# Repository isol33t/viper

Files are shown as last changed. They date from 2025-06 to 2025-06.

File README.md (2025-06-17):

# Duck Viper v1 PCB - Open Source Upgrade

⚠️ **Work in Progress** - This project is currently under development

Inspired by [Automated keyboard PCB design with ergogen and kbplacer by adamws](https://adamws.github.io/keyboard-pcb-design-with-ergogen-and-kbplacer/) & its [dockerfile](https://github.com/adamws/kicad-kbplacer/blob/develop/examples/absolem-ergogen/Dockerfile).

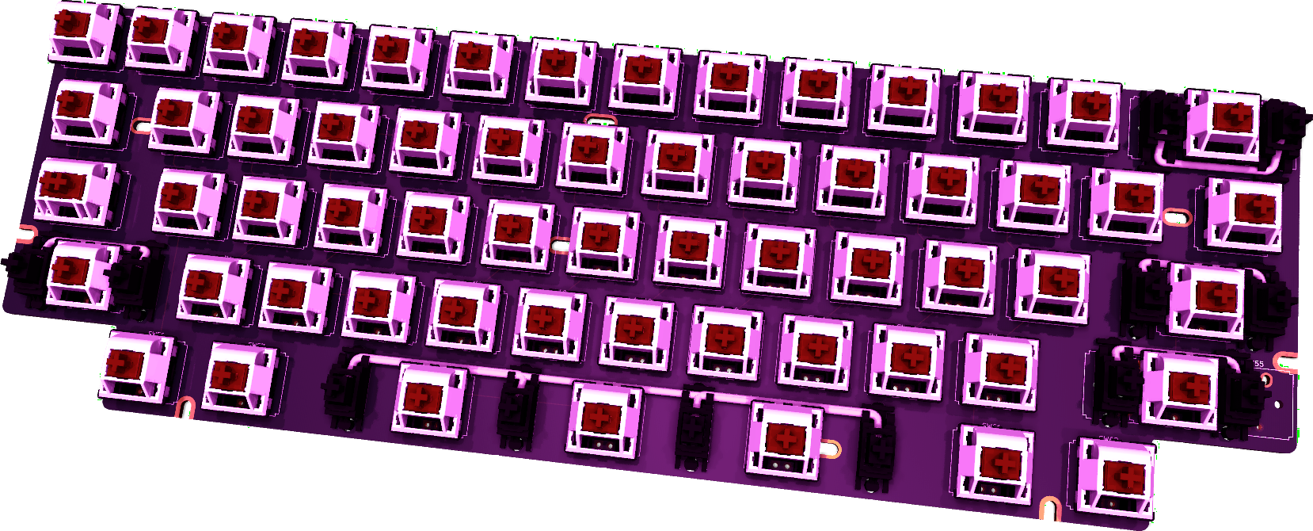
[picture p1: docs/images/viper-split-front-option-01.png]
Duck Viper v1 Render WIP


<!-- <img src="docs/images/viper-split-front-option-02.png" alt="Duck Viper v1 Render WIP" width="75%">

<img src="docs/images/viper-split-back-unrouted.png" alt="Duck Viper v1 Render WIP" width="75%"> -->

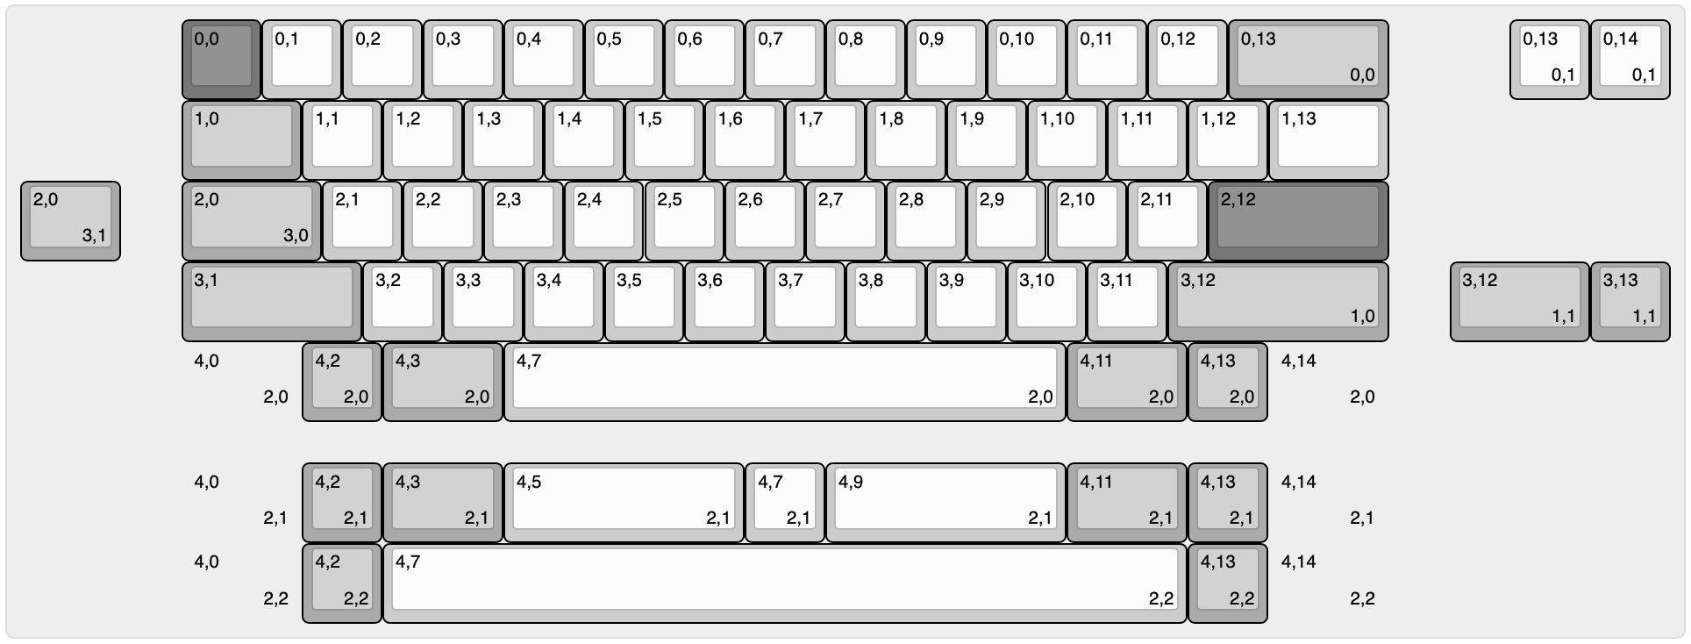
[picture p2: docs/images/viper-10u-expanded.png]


## Overview

An open-source PCB design for the Duck Viper v1 keyboard with hardware upgrades. This project focuses on transparency and community collaboration while building upon existing open-source resources.

**Disclaimer:** I'm not an electrical engineer - this project represents my attempt at "putting the parts together" using available community resources, guides, and libraries. Community feedback and contributions are greatly appreciated!

(Planned *) Upgrades: 
- USB-C Connector
- ESD
- Separate Caps Lock LED
- - RGB Underglow *
- - Additional switches for Split HHKB Bottom Row *
- - MXLockLed *

## Design Philosophy

- **Open Source First**: All design files, schematics, and documentation will be freely available
- **Community Driven**: Built using existing open-source libraries and community knowledge
- **Transparency**: Design decisions and trade-offs documented for others to learn from

## Current Status

<p align="left">
  Duck Viper v1 IC schematic WIP
</p>

[Link to PDF](hardware/schematic.pdf)

### Design Questions (Help Needed!)

**1. QFN vs QFP Package Decision**
- **QFN Pros**: Required for split HHKB layout with IC positioned between Caps Lock and A (see Voyager60 reference)
- **QFN Cons**: Hand soldering difficulty increases prototype cost (~$20 per PCB for 5-unit orders with just an assembled QFN IC vs ~$10 for 5 PCBs ex. assembly)
- **QFP**: Easier to hand solder but may not fit desired layout constraints due to additional stabilizer requirements for split HHKB

QFN IC placement mock-up:

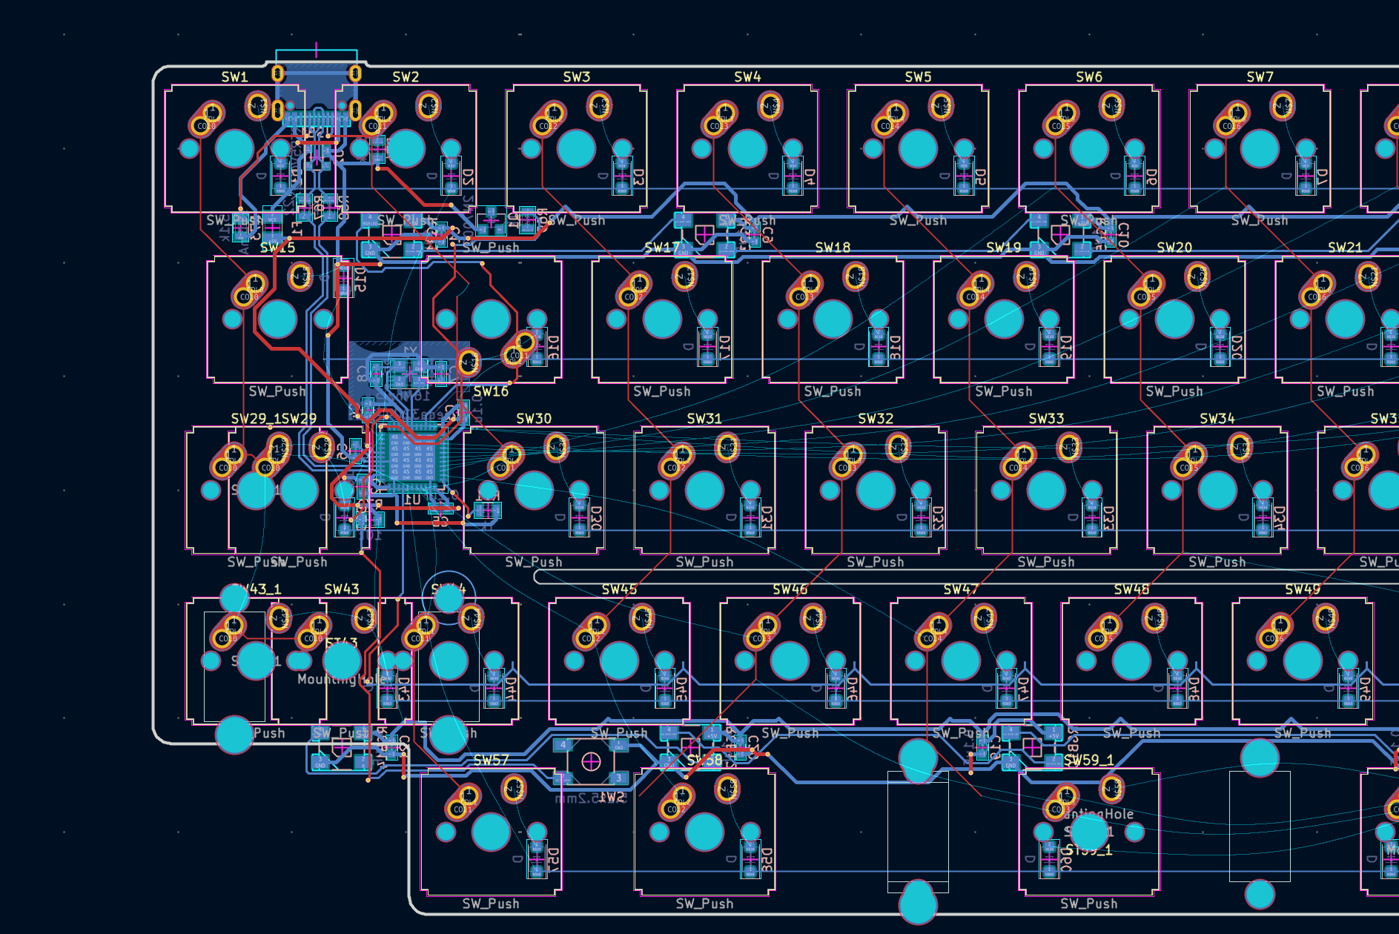
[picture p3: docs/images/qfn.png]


*If going QFN route, schematic verification help would be greatly appreciated!*

## Supported Layouts

kbplacer can use via for switch placement & requires via for collapsing a KLE layout

VIA spec https://www.caniusevia.com/docs/layouts#overview uses KLE raw, but not kle.com's raw json
VIA spec based on [wt60_d](https://github.com/the-via/keyboards/blob/9da730d66a00c3ca1b9b9ac7e7078fc221432501/v3/wilba_tech/wt60_d/wt60_d.json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)

```
python -m kbplacer.kle_serial -in -in kle/keyboard-layout-via-10u.json -inform KLE_VIA -out keyboard-layout-collapsed.json -outform KLE_RAW -collapse
```

- Forked [duck_viper](https://adamws.github.io/keyboard-pcbs/#duck-eagle_viper-v2-eagle_viper)

### Split HHKB, 10u

[KLE permalink](https://keyboard-layout-editor.com/##@@_x:2&c=%23777777%3B&=0,0&_c=%23cccccc%3B&=0,1&=0,2&=0,3&=0,4&=0,5&=0,6&=0,7&=0,8&=0,9&=0,10&=0,11&=0,12&_c=%23aaaaaa&w:2%3B&=0,13%0A%0A%0A0,0&_x:1.5&c=%23cccccc%3B&=0,13%0A%0A%0A0,1&=0,14%0A%0A%0A0,1%3B&@_x:2&c=%23aaaaaa&w:1.5%3B&=1,0&_c=%23cccccc%3B&=1,1&=1,2&=1,3&=1,4&=1,5&=1,6&=1,7&=1,8&=1,9&=1,10&=1,11&=1,12&_w:1.5%3B&=1,13%3B&@_c=%23aaaaaa&w:1.25%3B&=2,0%0A%0A%0A3,1&_x:0.75&w:1.75%3B&=2,0%0A%0A%0A3,0&_c=%23cccccc%3B&=2,1&=2,2&=2,3&=2,4&=2,5&=2,6&=2,7&=2,8&=2,9&=2,10&=2,11&_c=%23777777&w:2.25%3B&=2,12%3B&@_x:2&c=%23aaaaaa&w:2.25%3B&=3,1&_c=%23cccccc%3B&=3,2&=3,3&=3,4&=3,5&=3,6&=3,7&=3,8&=3,9&=3,10&=3,11&_c=%23aaaaaa&w:2.75%3B&=3,12%0A%0A%0A1,0&_x:0.75&w:1.75%3B&=3,12%0A%0A%0A1,1&=3,13%0A%0A%0A1,1%3B&@_x:2&w:1.5&d:true%3B&=4,0%0A%0A%0A2,0&=4,2%0A%0A%0A2,0&_w:1.5%3B&=4,3%0A%0A%0A2,0&_c=%23cccccc&w:7%3B&=4,7%0A%0A%0A2,0&_c=%23aaaaaa&w:1.5%3B&=4,11%0A%0A%0A2,0&=4,13%0A%0A%0A2,0&_w:1.5&d:true%3B&=4,14%0A%0A%0A2,0%3B&@_x:2&y:0.5&w:1.5&d:true%3B&=4,0%0A%0A%0A2,1&=4,2%0A%0A%0A2,1&_w:1.5%3B&=4,3%0A%0A%0A2,1&_c=%23cccccc&w:3%3B&=4,5%0A%0A%0A2,1&=4,7%0A%0A%0A2,1&_w:3%3B&=4,9%0A%0A%0A2,1&_c=%23aaaaaa&w:1.5%3B&=4,11%0A%0A%0A2,1&=4,13%0A%0A%0A2,1&_w:1.5&d:true%3B&=4,14%0A%0A%0A2,1%3B&@_x:2&w:1.5&d:true%3B&=4,0%0A%0A%0A2,2&=4,2%0A%0A%0A2,2&_c=%23cccccc&w:10%3B&=4,7%0A%0A%0A2,2&_c=%23aaaaaa%3B&=4,13%0A%0A%0A2,2&_w:1.5&d:true%3B&=4,14%0A%0A%0A2,2)

l33t

<details>
<summary>KLE Raw data, expanded</summary>
```
[{"x": 2, "c": "#777777"}, "0,0", {"c": "#cccccc"}, "0,1", "0,2", "0,3", "0,4", "0,5", "0,6", "0,7", "0,8", "0,9", "0,10", "0,11", "0,12", {"c": "#aaaaaa", "w": 2}, "0,13\n\n\n0,0", {"x": 1.5, "c": "#cccccc"}, "0,13\n\n\n0,1", "0,14\n\n\n0,1"],
[{"x": 2, "c": "#aaaaaa", "w": 1.5}, "1,0", {"c": "#cccccc"}, "1,1", "1,2", "1,3", "1,4", "1,5", "1,6", "1,7", "1,8", "1,9", "1,10", "1,11", "1,12", {"w": 1.5}, "1,13"],
[{"c": "#aaaaaa", "w": 1.25}, "2,0\n\n\n3,1", {"x": 0.75, "w": 1.75}, "2,0\n\n\n3,0", {"c": "#cccccc"}, "2,1", "2,2", "2,3", "2,4", "2,5", "2,6", "2,7", "2,8", "2,9", "2,10", "2,11", {"c": "#777777", "w": 2.25}, "2,12"],
[{"x": 2, "c": "#aaaaaa", "w": 2.25}, "3,1", {"c": "#cccccc"}, "3,2", "3,3", "3,4", "3,5", "3,6", "3,7", "3,8", "3,9", "3,10", "3,11", {"c": "#aaaaaa", "w": 2.75}, "3,12\n\n\n1,0", {"x": 0.75, "w": 1.75}, "3,12\n\n\n1,1", "3,13\n\n\n1,1"],
[{"x": 2, "w": 1.5, "d": true}, "4,0\n\n\n2,0", "4,2\n\n\n2,0", {"w": 1.5}, "4,3\n\n\n2,0", {"c": "#cccccc", "w": 7}, "4,7\n\n\n2,0", {"c": "#aaaaaa", "w": 1.5}, "4,11\n\n\n2,0", "4,13\n\n\n2,0", {"w": 1.5, "d": true}, "4,14\n\n\n2,0"],
[{"x": 2, "y": 0.5, "w": 1.5, "d": true}, "4,0\n\n\n2,1", "4,2\n\n\n2,1", {"w": 1.5}, "4,3\n\n\n2,1", {"c": "#cccccc", "w": 3}, "4,5\n\n\n2,1", "4,7\n\n\n2,1", {"w": 3}, "4,9\n\n\n2,1", {"c": "#aaaaaa", "w": 1.5}, "4,11\n\n\n2,1", "4,13\n\n\n2,1", {"w": 1.5, "d": true}, "4,14\n\n\n2,1"],
[{"x": 2, "w": 1.5, "d": true}, "4,0\n\n\n2,2", "4,2\n\n\n2,2", {"c": "#cccccc", "w": 10}, "4,7\n\n\n2,2", {"c": "#aaaaaa"}, "4,13\n\n\n2,2", {"w": 1.5, "d": true}, "4,14\n\n\n2,2"]
```
</details>

[KLE permalink](https://keyboard-layout-editor.com/##@@_x:2&c=%23777777%3B&=0,0&_c=%23cccccc%3B&=0,1&=0,2&=0,3&=0,4&=0,5&=0,6&=0,7&=0,8&=0,9&=0,10&=0,11&=0,12&_c=%23aaaaaa&w:2%3B&=0,13%0A%0A%0A0,0&_x:-2&c=%23cccccc%3B&=0,13%0A%0A%0A0,1&=0,14%0A%0A%0A0,1%3B&@_x:2&c=%23aaaaaa&w:1.5%3B&=1,0&_c=%23cccccc%3B&=1,1&=1,2&=1,3&=1,4&=1,5&=1,6&=1,7&=1,8&=1,9&=1,10&=1,11&=1,12&_w:1.5%3B&=1,13%3B&@_x:2&c=%23aaaaaa&w:1.75%3B&=2,0%0A%0A%0A3,0&_x:-1.75&w:1.25%3B&=2,0%0A%0A%0A3,1&_x:0.5&c=%23cccccc%3B&=2,1&=2,2&=2,3&=2,4&=2,5&=2,6&=2,7&=2,8&=2,9&=2,10&=2,11&_c=%23777777&w:2.25%3B&=2,12%3B&@_x:2&c=%23aaaaaa&w:2.25%3B&=3,1&_c=%23cccccc%3B&=3,2&=3,3&=3,4&=3,5&=3,6&=3,7&=3,8&=3,9&=3,10&=3,11&_c=%23aaaaaa&w:2.75%3B&=3,12%0A%0A%0A1,0&_x:-2.75&w:1.75%3B&=3,12%0A%0A%0A1,1&=3,13%0A%0A%0A1,1%3B&@_x:3.5%3B&=4,2%0A%0A%0A2,0&_w:1.5%3B&=4,3%0A%0A%0A2,0&_c=%23cccccc&w:3%3B&=4,5%0A%0A%0A2,1&_x:-3&w:7%3B&=4,7%0A%0A%0A2,0&_x:-3&w:3%3B&=4,9%0A%0A%0A2,1&_c=%23aaaaaa&w:1.5%3B&=4,11%0A%0A%0A2,0&=4,13%0A%0A%0A2,0)

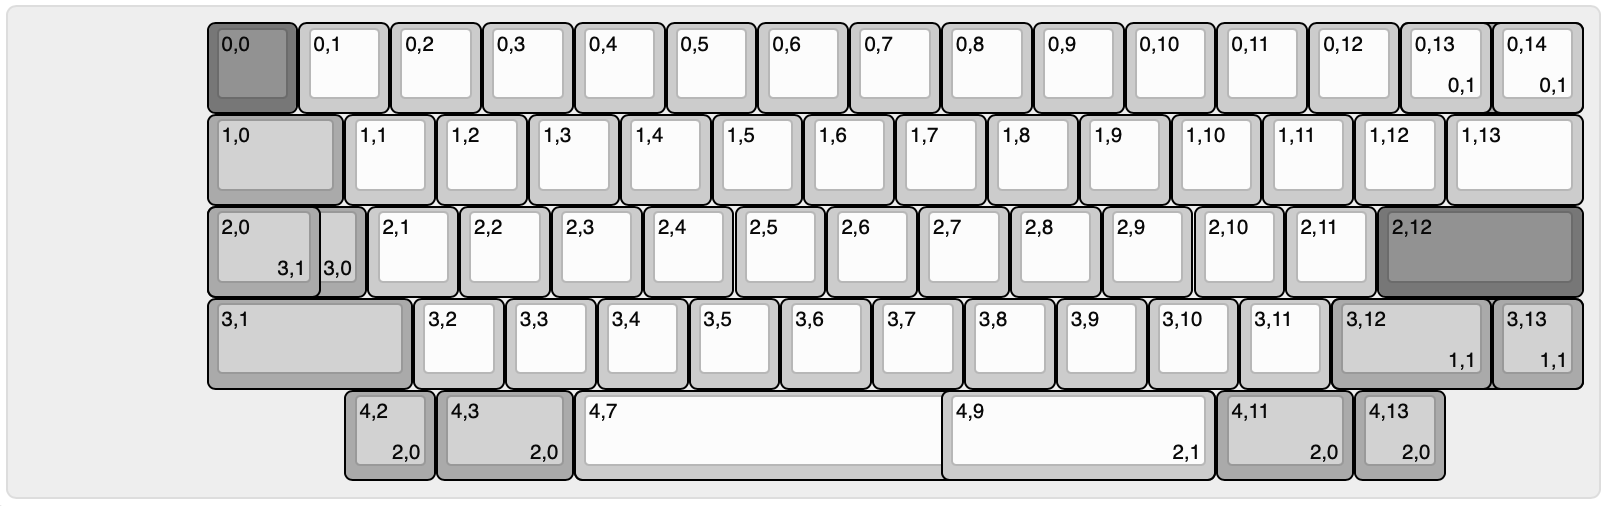
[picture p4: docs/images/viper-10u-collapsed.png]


<details>
<summary>KLE Raw data, collapsed</summary>
```
[{"x": 2, "c": "#777777"}, "0,0", {"c": "#cccccc"}, "0,1", "0,2", "0,3", "0,4", "0,5", "0,6", "0,7", "0,8", "0,9", "0,10", "0,11", "0,12", {"c": "#aaaaaa", "w": 2}, "0,13\n\n\n0,0", {"x": -2, "c": "#cccccc"}, "0,13\n\n\n0,1", "0,14\n\n\n0,1"],
[{"x": 2, "c": "#aaaaaa", "w": 1.5}, "1,0", {"c": "#cccccc"}, "1,1", "1,2", "1,3", "1,4", "1,5", "1,6", "1,7", "1,8", "1,9", "1,10", "1,11", "1,12", {"w": 1.5}, "1,13"],
[{"x": 2.0, "c": "#aaaaaa", "w": 1.75}, "2,0\n\n\n3,0", {"x": -1.75, "w": 1.25}, "2,0\n\n\n3,1", {"x": 0.5, "c": "#cccccc"}, "2,1", "2,2", "2,3", "2,4", "2,5", "2,6", "2,7", "2,8", "2,9", "2,10", "2,11", {"c": "#777777", "w": 2.25}, "2,12"],
[{"x": 2, "c": "#aaaaaa", "w": 2.25}, "3,1", {"c": "#cccccc"}, "3,2", "3,3", "3,4", "3,5", "3,6", "3,7", "3,8", "3,9", "3,10", "3,11", {"c": "#aaaaaa", "w": 2.75}, "3,12\n\n\n1,0", {"x": -2.75, "w": 1.75}, "3,12\n\n\n1,1", "3,13\n\n\n1,1"],
[{"x": 3.5}, "4,2\n\n\n2,0", {"w": 1.5}, "4,3\n\n\n2,0", {"c": "#cccccc", "w": 3}, "4,5\n\n\n2,1", {"x": -3.0, "w": 7}, "4,7\n\n\n2,0", {"x": -3.0, "w": 3}, "4,9\n\n\n2,1", {"c": "#aaaaaa", "w": 1.5}, "4,11\n\n\n2,0", "4,13\n\n\n2,0"]
```
</details>

## Development Environment Setup

### Hardware Design (KiCad)

**Requirements:**
- KiCad 9.0 or later
- Git for version control
- - python3
- - docker

**Setup:**
```bash
# Clone the repository
git clone [repository-url]
cd duck-viper-v1-pcb

# Open the project in KiCad
# File -> Open Project -> duck-viper-v1.kicad_pro
```

**Setup for adamws/kbplacer:**
```bash
# Clone the repository
git clone [repository-url]
cd duck-viper-v1-pcb
python3 -m venv .venv
source .venv/bin/activate
python3 -m pip install .

python -m kbplacer.kle_serial -in kle/keyboard-layout-via.json -inform KLE_VIA -out kle/keyboard-layout-collapsed.json -outform KLE_INTERNAL -collapse
python tools/layout2url.py -in keyboard-layout-collapsed.json|pbcopy

# Open the project in KiCad
# File -> Open Project -> duck-viper-v1.kicad_pro
```

**linux**
```bash
python3 -m venv .venv --system-site-packages
source .venv/bin/activate
pip install .

# test kicad
python -c "import pcbnew; print(pcbnew.Version())"
```

**Libraries Used:**
- [AcheronProject/AlexandriaLibrary](https://github.com/AcheronProject/AlexandriaLibrary)
- Community keyboard libraries (specific sources TBD)

### Firmware Development

*Detailed firmware setup instructions will be added as development progresses.*

### Manufacturing Files

Generation of Gerber files, pick-and-place files, and BOM will be documented once design is finalized.

## Acknowledgments

This project builds upon the incredible work of the open-source keyboard community. Specific libraries, guides, and resources used will be documented as the project progresses.

## Contributing

As a learning project, I welcome:
- Schematic reviews and feedback
- Design suggestions and improvements
- Documentation contributions
- Testing and validation help

## Thanks yo

This project is inspired by [Automated Keyboard PCB design with ergogen and kbplacer](https://github.com/adamws/kicad-kbplacer/tree/master/examples/absolem-ergogen). Still, it's far from being fully automated.

- adamws/kicad-kbplacer
- https://github.com/ruiqimao/keyboard-pcb-guide
- https://wiki.ai03.com/books/pcb-design
- https://github.com/evyd13/plain60-b
- https://github.com/evyd13/plain60-c
- https://www.masterzen.fr/2020/05/03/designing-a-keyboard-part-1/

## License

[MIT](LICENSE)

---

*This project is a learning exercise in PCB design. Use at your own risk and always verify designs before manufacturing.*

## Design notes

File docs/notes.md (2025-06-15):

# Duck Viper v1 - Design Notes

*Consolidated notes and research for the Duck Viper v1 PCB project*

## Design Decision Log

- 2025-05: restart PCB project
- - manual placement of basic viper pcb, no leds
- - discovered adamws/kicad-kbplacer
- - forked [4pplet/eagle_viper_rep_rev_b](https://adamws.github.io/keyboard-pcbs/#4pplet-eagle_viper_rep_rev_b)
- 2025-06:
- - added ws2818b leds
- - removed iso enter/split left shift
- - considering split hhkb layout
- - - requires qfn instead of qfp
- footprint placement
- - voyager60 usb-c
- - voyager60 qfn 
- - gh60 qfp
- [decoupling cap placement](https://components101.com/articles/decoupling-capacitor-vs-bypass-capacitors-working-and-applications)
- - The positioning involves two different capacitors, consider a capacitor of capacitance 10µF placed away from the IC which is used to smooth out the low frequency changes in the power supply and a 0.1 µF capacitor kept closer to the IC which is used to smooth the high frequency changes in the power supply.
- - 10µF placed away
- - .1µF close to pins
- - for voyager60: move 10µF cap further away
- - add additional .1µF cap where 10µF currently sits
- improve kicad docs
- nice template, https://github.com/nguyen-v/KiCAD_Templates/tree/master
- - eeschema
- - https://www.youtube.com/watch?v=_ZjyeltLMAg
- - pcbnew
- - https://www.youtube.com/watch?v=_ZjyeltLMAg&list=WL&index=109&t=1305s

You probably shouldn't connect the USB shield to GND, or if you do it should be through a cap and something like a 10M resistor. This is to avoid emitting unwanted RFI.
!
https://geekhack.org/index.php?topic=48851.msg2356672#msg2356672

- jp60
- - usb-c shield to earth, earth to ferrite bead to gnd
- tsuki
- - usb-c shield to junction, 1 to 4.7nF cap then gnd, another to 1M resistor then GND
- - no ferrite bead
- - mounting hole to case ESD
- - case mounting hole ESD to junction, 1 to 4.7nF cap then gnd, another to 1M resistor then GND
- https://geekhack.org/index.php?topic=48851.msg2361099#msg2361099
- - bpiphany: For the USB shield there seem to be as many different recommendations as there are possible ways to combine resistor/capacitor/inductor networks or directly tie it to GND or floating. It's hard to tell what to use when/where/why.
- ground plane crystal: https://geekhack.org/index.php?topic=48851.msg2406698#msg2406698
- - I think it's more about keeping the "noise" from the oscillator away from the plane. You ideally want to surround the oscillator circuit with ground, on the sides and below. You then connect this "cage" at a single point to the board ground plane.
- resistors for usb close to usb or mcu?
- - https://geekhack.org/index.php?topic=48851.msg2481179#msg2481179
- - ESD/EMI protection deivces should be placed near USB receptacle while termination(impedance matcning) resistors should be placed near controller.
- - We already know empirically that it doesn't matter very much for keyboards, though, this simple design guide will be still helpful for us.
- [Why does the ATmega32 have two VCC & GND pins?](https://microchip.my.site.com/s/article/Why-does-the-ATmega32-have-two-VCC-GND-pins)

- alternative docker idea
- create atmega template with linked sheets
- copy to docker build container
- create new schematics -> path of linked sheets
- - run save-schematic-script
- export netlist from schematic
- - includes linked sheets, in theory
- kinet2pcb complete netlist
- kbplacer/pos2orient/???

## Component Sourcing

I found a box of components, from a previous attempt, based on [evyd13/plain60-c](https://github.com/evyd13/plain60-c#bill-of-materials-bom), yet some are currently out ot stock.

- Stick with 0805 packages
- Asian brands are Okay
- x7r capacitors are preferred
- ... by a single brand, possibly hre?
- - uniroyal
- - nexperia
- - https://www.lcsc.com/supplier/featured-asian-brands
- - qfp https://www.lcsc.com/product-detail/Microcontrollers-MCU-MPU-SOC_Microchip-Tech-ATMEGA32U4-AU_C44854.html
- - qfn https://www.lcsc.com/product-detail/Microcontroller-Units-MCUs-MPUs-SOCs_Microchip-Tech-ATMEGA32U4-MU_C112161.html

## Quick Reference

### Key Decisions
- **Layout**: Split HHKB (requires QFN placement between Caps Lock and A)
- **Components**: 0805 package (already sourced but wrong dimensions, currently using SOD123 & QFP)
- **Connector**: USB-C (seems to fit!)
- **Microcontroller**: ATmega32U4 (QFN vs QFP decision pending)
- **Reference Design**: Tsuki, JP60, Voyager60, plain60-b/c

### Current Status
- ✅ Dev environment setup (Mac + Linux + Docker)
- ✅ KLE layouts created (collapsed/uncollapsed variants)
- ✅ Kbplacer and kle2netlist working
- ✅ Local library Git repo created
- ⚠️ **QFN prototyping cost: ~$17.60 per PCB** (PCBWay assembly)
- 🔄 Library decisions pending (Acheron vs others)
- 🔄 ESD protection component selection

---

## Development Environment ✅

### Tools Setup
- **Mac**: Python venv with kbplacer, pyyaml, pyurlon, kle2netlist
- **Linux**: KiCad global python modules + Docker support
- **Kbplacer**: Working with dockerized dev branch
- **Kle2netlist**: Integrated with ATmega template

### Workflows Tested
- ✅ Manual kbplacer-kicad workflow
- ✅ Dockerized development environment
- ✅ KLE → netlist → KiCad pipeline

---

## Layout & Mechanical ✅

### KLE Layouts Complete
- **Uncollapsed**: Raw, Internal, Via variants
- **Collapsed**: Raw, Internal variants
- **Screenshots and URLs**: Documented
- **Stepped Caps**: Measured and positioned
  - Regular to stepped caps offset: -4.7625mm
  - Stepped caps to edge: 11.58125mm
  - Grave (`) to stepped caps: x+2.38125, y+38.1

### PCB Outline Placement ✅
- **Position relative to K_TILDE**: X=133.35, Y=38.085
- **PCB Dimensions**: 285mm × 94.6mm

### Stabilizer Configuration
- **Normal**: Backspace
- **Flipped 180°**: Space, LShift, RShift, Enter
- **ISO**: ST28_1 270° (conflicts with WS2812B LED placement)

---

## Component Research

https://www.lcsc.com/product-detail/Diodes-ESD_STMicroelectronics_USBLC6-2SC6_USBLC6-2SC6_C7519.html

### Microcontroller Package Decision
**QFN (Current Choice):**
- ✅ Required for split HHKB (fits between Caps & A)
- ❌ Can't hand solder easily
- ❌ Assembly cost: $17.60 per PCB (5 PCBs via PCBWay)
- ✅ 5 QFN ATmegas already sourced

**QFP Alternative:**
- ✅ Hand solderable
- ❌ May not fit split HHKB layout constraints

### Component Packages & Sourcing
**Current Stock (Wrong Dimensions):**
- 0805 capacitors ✅
- 0805 resistors ✅
- USB-C connector ✅ (seems to fit!)
- 5× QFN ATmega32U4 ✅

**Component Updates Needed:**
- Update footprints from current to 0805
- All non-LED board parts sourced but need dimension fixes

### ESD Protection Options
**USBLC6-2SC6** (Current stock):
- Very low capacitance ESD protection
- STMicroelectronics part

**PRTR5V0U2X** (JP60 reference):
- Ultra low capacitance double rail-to-rail protection
- Nexperia part

**TPD2S017** (kle2netlist template):
- 2-channel 5.5V, 1pF, ±11kV protection with EMI filtering
- TI part

---

## Library Decisions (Pending)

### Symbol Libraries
- **Acheron**: Selected ✅
- Reference components from Tsuki schematic:
  - ResistorSMD 0603_1608Metric
  - CapSMD 0603
  - ATQFP44_10x10mm_P0.8
  - Crystal_SMD_3225-4Pin
  - SW_SPST_TL3342
  - SOT-23-6 ESD
  - USB_C_Receptacle_XKB_U262-16XN-4BVC11

### Footprint Libraries (To Decide)
- **Acheron**: Connectors, mounting holes
- **Kiswitch**: Connectors, stabilizers  
- **MX_V2**: Switch LEDs
- **Local lib**: Viper outline ✅

### Local Library ✅
- Viper outline ✅
- ISP header (needed? QMK has soft reset)
- Crystal (custom 3-pad vs 4-pad - why?)
- Mounting holes (Acheron reference)
- USB connectors

---

## LED Matrix & RGB

### Switch LEDs ✅
- Circuit tested with old Viper repo
- Separate circuit for Caps Lock LED planned

### RGB LEDs (WS2812B)
**Component**: TZ_3528S2RGB_5V (JLCPCB: C26159669)
- 3528 format footprint
- **Conflict**: ISO Enter OR RGB LEDs (choosing RGB)
- Reference circuits: Tsuki, Voyager
- VCC/VDD/5V power considerations

### LED Matrix Integration ✅
- Successfully added 2x2 LED matrix to test
- ATmega template integration working

---

## Manufacturing Planning

### Assembly Costs
- **QFN Assembly**: $88 for 5 PCBs (PCBWay) = $17.60 each
- Cost excludes MCU component cost
- QFN hand soldering attempted but challenging

### PCB Specifications
- **Connector**: USB-C (fits in current design)
- **ESD**: Update schematic for chosen component
- **Finish**: Research Viper/Sprit/GH60 comparisons needed

---

## Future Features & Improvements

### Planned Features
- **MX Lock Caps**: LED support (reference: GH60PCB)
- **STM32 Variants**: Joker48/64 circuitry reference
- **Split HHKB**: Additional layout exploration

### Key Mapping & Special Keys
**Flipped Keys** (from bad/viper_v1):
- KC_GRV, KC_1, KC_2, KC_Q
- KC_CAPS, KC_CAPS_STEP, KC_A, KC_H
- KC_SHIFT, KC_SHIFT_SHORT, KC_ISO, KC_Z
- KC_SPACE, KC_RIGHT_ALT

---

## Completed Tasks ✅

### Development Setup
- [x] Local lib Git repo
- [x] Viper outline
- [x] ISP header
- [x] Cleanup repos (Viper, Voyager, Keebio, GH60, STM32 LED matrix)
- [x] Dev environment (Mac + Linux)
- [x] KLE layouts (all variants)
- [x] Kbplacer-KiCad integration
- [x] LED matrix testing
- [x] 2x2 test PCB with LED matrix + ATmega template

### Measurements & Positioning
- [x] Stepped caps measurements and positioning
- [x] PCB outline placement calculations
- [x] Key matrix positioning

---

## Pending Tasks

### Critical Path
- [ ] Finalize library decisions (Acheron vs alternatives)
- [ ] Test libraries in dockerized environment
- [ ] Complete RGB LED integration (non-ISO)
- [ ] Stabilizer placement (normal + flipped orientations)
- [ ] Component dimension updates (0805 transition)

### Secondary
- [ ] Schematic verification (community help needed)
- [ ] USB D+/D- net naming
- [ ] ATmega pin assignments optimization
- [ ] Assembly cost optimization research

---

## References & Resources

### Key Projects
- **Tsuki**: Primary schematic reference ⭐
- **Voyager60**: QFN placement reference
- **Keebio**: Component references
- **GH60**: Finish comparisons

### Tools & Documentation
- [Keyboard PCB Design Guide](https://adamws.github.io/keyboard-pcb-design-with-ergogen-and-kbplacer/)
- [KLE](https://www.keyboard-layout-editor.com)
- [KLE Converter](https://keyboard-tools.xyz/kle-converter)
- [kle2netlist](https://github.com/adamws/kle2netlist/tree/develop)
- [Via Layout Docs](https://www.caniusevia.com/docs/layouts/)
- [AI03 PCB Design Wiki](https://wiki.ai03.com/books/pcb-design/page/microcontroller-design)
- [Kbplacer Annotation Guide](https://github.com/adamws/kicad-kbplacer/blob/master/docs/annotation_guide.md)
- [masterzen design guide](https://www.masterzen.fr/2020/05/03/designing-a-keyboard-part-1/)

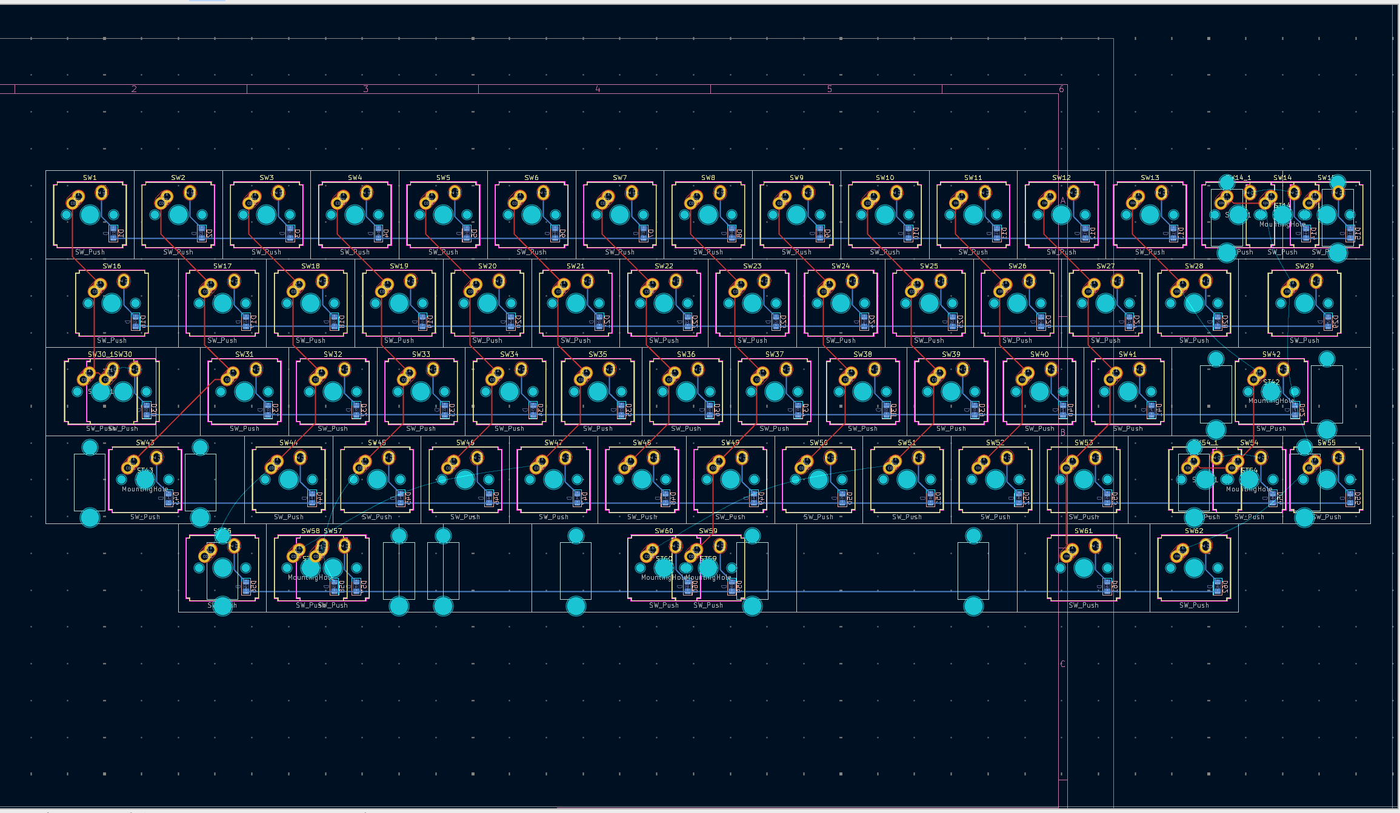
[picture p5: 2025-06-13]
docs/images/broken-bottom.png

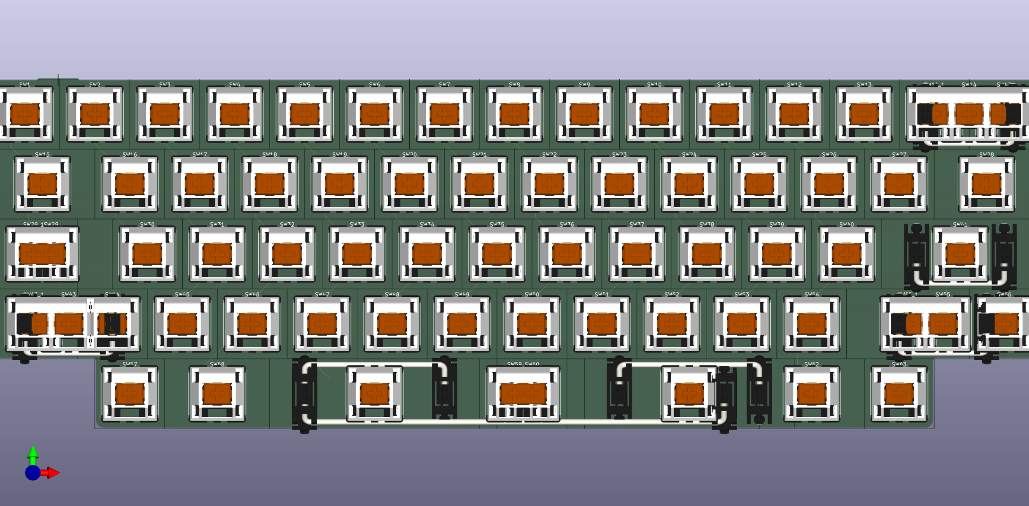
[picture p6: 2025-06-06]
docs/images/render.png

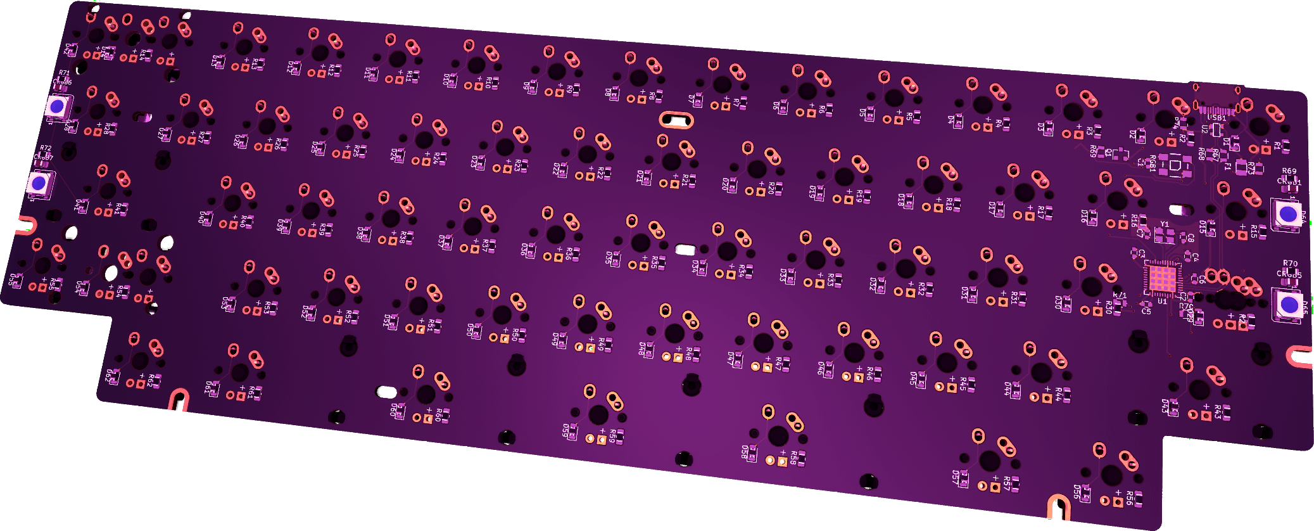
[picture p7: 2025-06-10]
docs/images/viper-split-back-unrouted.png

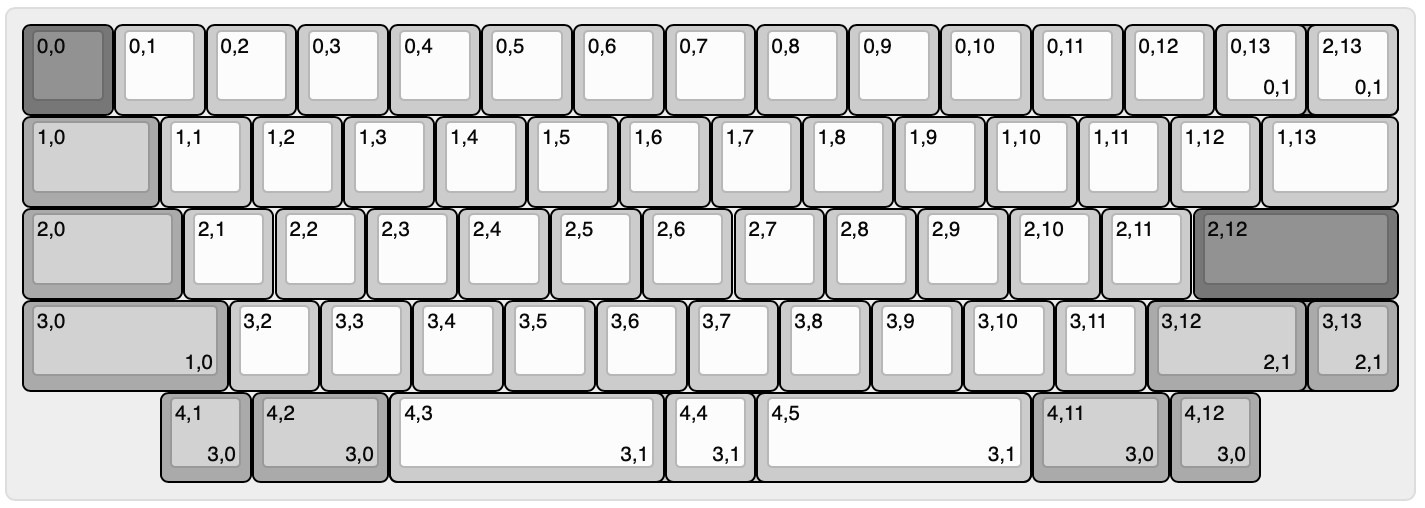
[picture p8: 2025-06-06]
docs/images/split-collapsed.png

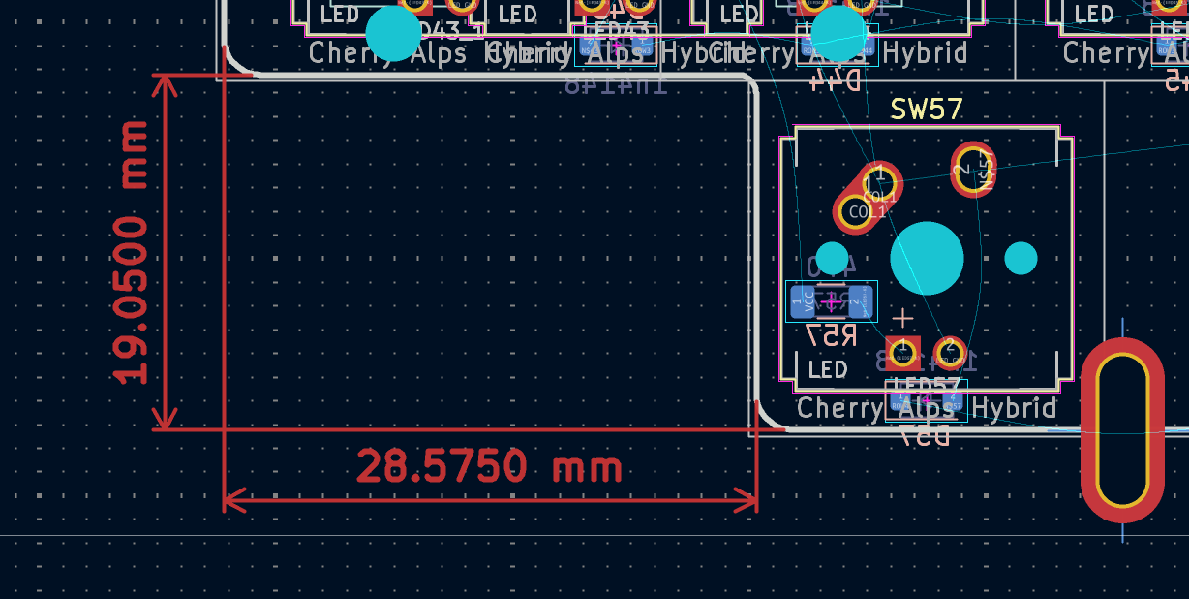
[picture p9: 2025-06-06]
docs/images/viper.png

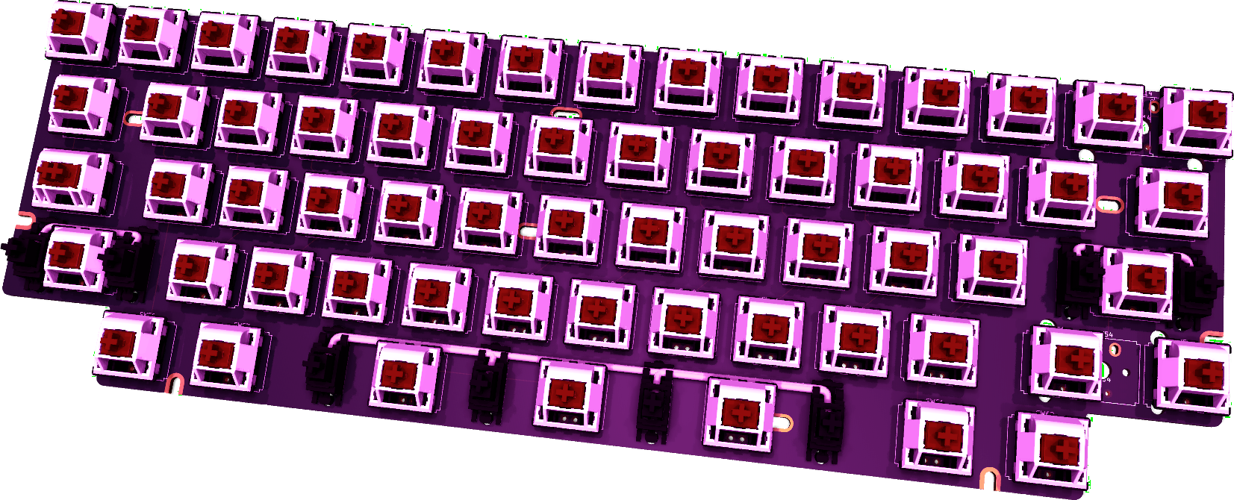
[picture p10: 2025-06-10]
docs/images/viper-split-front-option-02.png

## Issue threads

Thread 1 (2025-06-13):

PCB output from docker build has incorrect layout

isol33t, 2025-06-13:
TL;DR:
- currently, kbplacer in a docker (or locally for that matter, using kicad9.0.2 with kbplacer from PCM on macOS 15.4.1) places additional bottom row switches incorrectly.
- the 8u stabiliser is missing from automated builds

When I try to use [docker](https://github.com/isol33t/viper/blob/dev-kle2netlist/hardware/Dockerfile) to [build a PCB](https://github.com/isol33t/viper/blob/4d931042c1d1a1473b27abfa2af59fe0bfbce6e7/hardware/viper-10u-2025-06-13_11-10-14/viper-10u.kicad_pcb) with a [annotated VIA layout](https://github.com/isol33t/viper/blob/4d931042c1d1a1473b27abfa2af59fe0bfbce6e7/hardware/kle/keyboard-layout-via.json) which is collapsed during the build process, I notice the following:
- Additional bottom row switches and their stabilizers for a split HHKB layout (2x 3U) aren't placed correct.
- The additional 8u stabilizer is missing.
- Switches with overlapping footprints have a value such as SW30 SW30_1, still totaling 65 switches.

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

When I use the [kle.json](https://github.com/isol33t/viper/blob/4d931042c1d1a1473b27abfa2af59fe0bfbce6e7/hardware/viper-10u-2025-06-13_11-10-14/viper-10u-kle.json) from my build & submit it to [keyboard-tools.xyz](http://keyboard-tools.xyz), the bottom row is placed correct, yet there are 2 changes compared to the dockerbuild (as far as I can tell):
- Switch values just count from 1 to 65
- The kle.json file has been re-annotated, for instance, `backspace` becomes `0,16` & the color of  `\|` changes to `#aaaaaa` (which makes it a modifier key in the via spec)

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

Converting the [kle.json](https://github.com/isol33t/viper/blob/4d931042c1d1a1473b27abfa2af59fe0bfbce6e7/hardware/6d52fe96-3577-438b-9c42-944a9f39cb8f/keyboard/keyboard.json) from keyboard-tools.xyzs output to [`KLE_RAW`](https://github.com/isol33t/viper/blob/4d931042c1d1a1473b27abfa2af59fe0bfbce6e7/hardware/6d52fe96-3577-438b-9c42-944a9f39cb8f/keyboard/keyboard-raw.json) & submitting it my docker build gives me the same result.

- [KLE Expanded](https://keyboard-layout-editor.com/##@@_x:2&c=%23777777%3B&=0,0&_c=%23cccccc%3B&=0,1&=0,2&=0,3&=0,4&=0,5&=0,6&=0,7&=0,8&=0,9&=0,10&=0,11&=0,12&_c=%23aaaaaa&w:2%3B&=0,13%0A%0A%0A0,0&_x:1.5&c=%23cccccc%3B&=0,13%0A%0A%0A0,1&=0,14%0A%0A%0A0,1%3B&@_x:2&c=%23aaaaaa&w:1.5%3B&=1,0&_c=%23cccccc%3B&=1,1&=1,2&=1,3&=1,4&=1,5&=1,6&=1,7&=1,8&=1,9&=1,10&=1,11&=1,12&_w:1.5%3B&=1,13%3B&@_c=%23aaaaaa&w:1.25%3B&=2,0%0A%0A%0A3,1&_x:0.75&w:1.75%3B&=2,0%0A%0A%0A3,0&_c=%23cccccc%3B&=2,1&=2,2&=2,3&=2,4&=2,5&=2,6&=2,7&=2,8&=2,9&=2,10&=2,11&_c=%23777777&w:2.25%3B&=2,12%3B&@_x:2&c=%23aaaaaa&w:2.25%3B&=3,1&_c=%23cccccc%3B&=3,2&=3,3&=3,4&=3,5&=3,6&=3,7&=3,8&=3,9&=3,10&=3,11&_c=%23aaaaaa&w:2.75%3B&=3,12%0A%0A%0A1,0&_x:0.75&w:1.75%3B&=3,12%0A%0A%0A1,1&=3,13%0A%0A%0A1,1%3B&@_x:2&w:1.5&d:true%3B&=4,0%0A%0A%0A2,0&=4,2%0A%0A%0A2,0&_w:1.5%3B&=4,3%0A%0A%0A2,0&_c=%23cccccc&w:7%3B&=4,7%0A%0A%0A2,0&_c=%23aaaaaa&w:1.5%3B&=4,11%0A%0A%0A2,0&=4,13%0A%0A%0A2,0&_w:1.5&d:true%3B&=4,14%0A%0A%0A2,0%3B&@_x:2&y:0.5&w:1.5&d:true%3B&=4,0%0A%0A%0A2,1&=4,2%0A%0A%0A2,1&_w:1.5%3B&=4,3%0A%0A%0A2,1&_c=%23cccccc&w:3%3B&=4,5%0A%0A%0A2,1&=4,7%0A%0A%0A2,1&_w:3%3B&=4,9%0A%0A%0A2,1&_c=%23aaaaaa&w:1.5%3B&=4,11%0A%0A%0A2,1&=4,13%0A%0A%0A2,1&_w:1.5&d:true%3B&=4,14%0A%0A%0A2,1%3B&@_x:2&w:1.5&d:true%3B&=4,0%0A%0A%0A2,2&=4,2%0A%0A%0A2,2&_c=%23cccccc&w:10%3B&=4,7%0A%0A%0A2,2&_c=%23aaaaaa%3B&=4,13%0A%0A%0A2,2&_w:1.5&d:true%3B&=4,14%0A%0A%0A2,2)
- [KLE collapsed](https://keyboard-layout-editor.com/##@@_x:2&c=%23777777%3B&=0,0&_c=%23cccccc%3B&=0,1&=0,2&=0,3&=0,4&=0,5&=0,6&=0,7&=0,8&=0,9&=0,10&=0,11&=0,12&_c=%23aaaaaa&w:2%3B&=0,13%0A%0A%0A0,0&_x:-2&c=%23cccccc%3B&=0,13%0A%0A%0A0,1&=0,14%0A%0A%0A0,1%3B&@_x:2&c=%23aaaaaa&w:1.5%3B&=1,0&_c=%23cccccc%3B&=1,1&=1,2&=1,3&=1,4&=1,5&=1,6&=1,7&=1,8&=1,9&=1,10&=1,11&=1,12&_w:1.5%3B&=1,13%3B&@_x:2&c=%23aaaaaa&w:1.75%3B&=2,0%0A%0A%0A3,0&_x:-1.75&w:1.25%3B&=2,0%0A%0A%0A3,1&_x:0.5&c=%23cccccc%3B&=2,1&=2,2&=2,3&=2,4&=2,5&=2,6&=2,7&=2,8&=2,9&=2,10&=2,11&_c=%23777777&w:2.25%3B&=2,12%3B&@_x:2&c=%23aaaaaa&w:2.25%3B&=3,1&_c=%23cccccc%3B&=3,2&=3,3&=3,4&=3,5&=3,6&=3,7&=3,8&=3,9&=3,10&=3,11&_c=%23aaaaaa&w:2.75%3B&=3,12%0A%0A%0A1,0&_x:-2.75&w:1.75%3B&=3,12%0A%0A%0A1,1&=3,13%0A%0A%0A1,1%3B&@_x:3.5%3B&=4,2%0A%0A%0A2,0&_w:1.5%3B&=4,3%0A%0A%0A2,0&_c=%23cccccc&w:3%3B&=4,5%0A%0A%0A2,1&_x:-3&w:7%3B&=4,7%0A%0A%0A2,0&_x:-3&w:3%3B&=4,9%0A%0A%0A2,1&_c=%23aaaaaa&w:1.5%3B&=4,11%0A%0A%0A2,0&=4,13%0A%0A%0A2,0)
- [docker build log](https://github.com/isol33t/viper/tree/3cb8e976255d5e0f26320280a03c054df501b68b/hardware/viper-10u-2025-06-13_11-10-14)
- [keyboard-tools.xyz log](https://github.com/isol33t/viper/blob/3cb8e976255d5e0f26320280a03c054df501b68b/hardware/6d52fe96-3577-438b-9c42-944a9f39cb8f/logs/build.log)

ps. [via doesn't support stepped keys](https://www.caniusevia.com/docs/layouts/#kle-json-rules), something to look into later.

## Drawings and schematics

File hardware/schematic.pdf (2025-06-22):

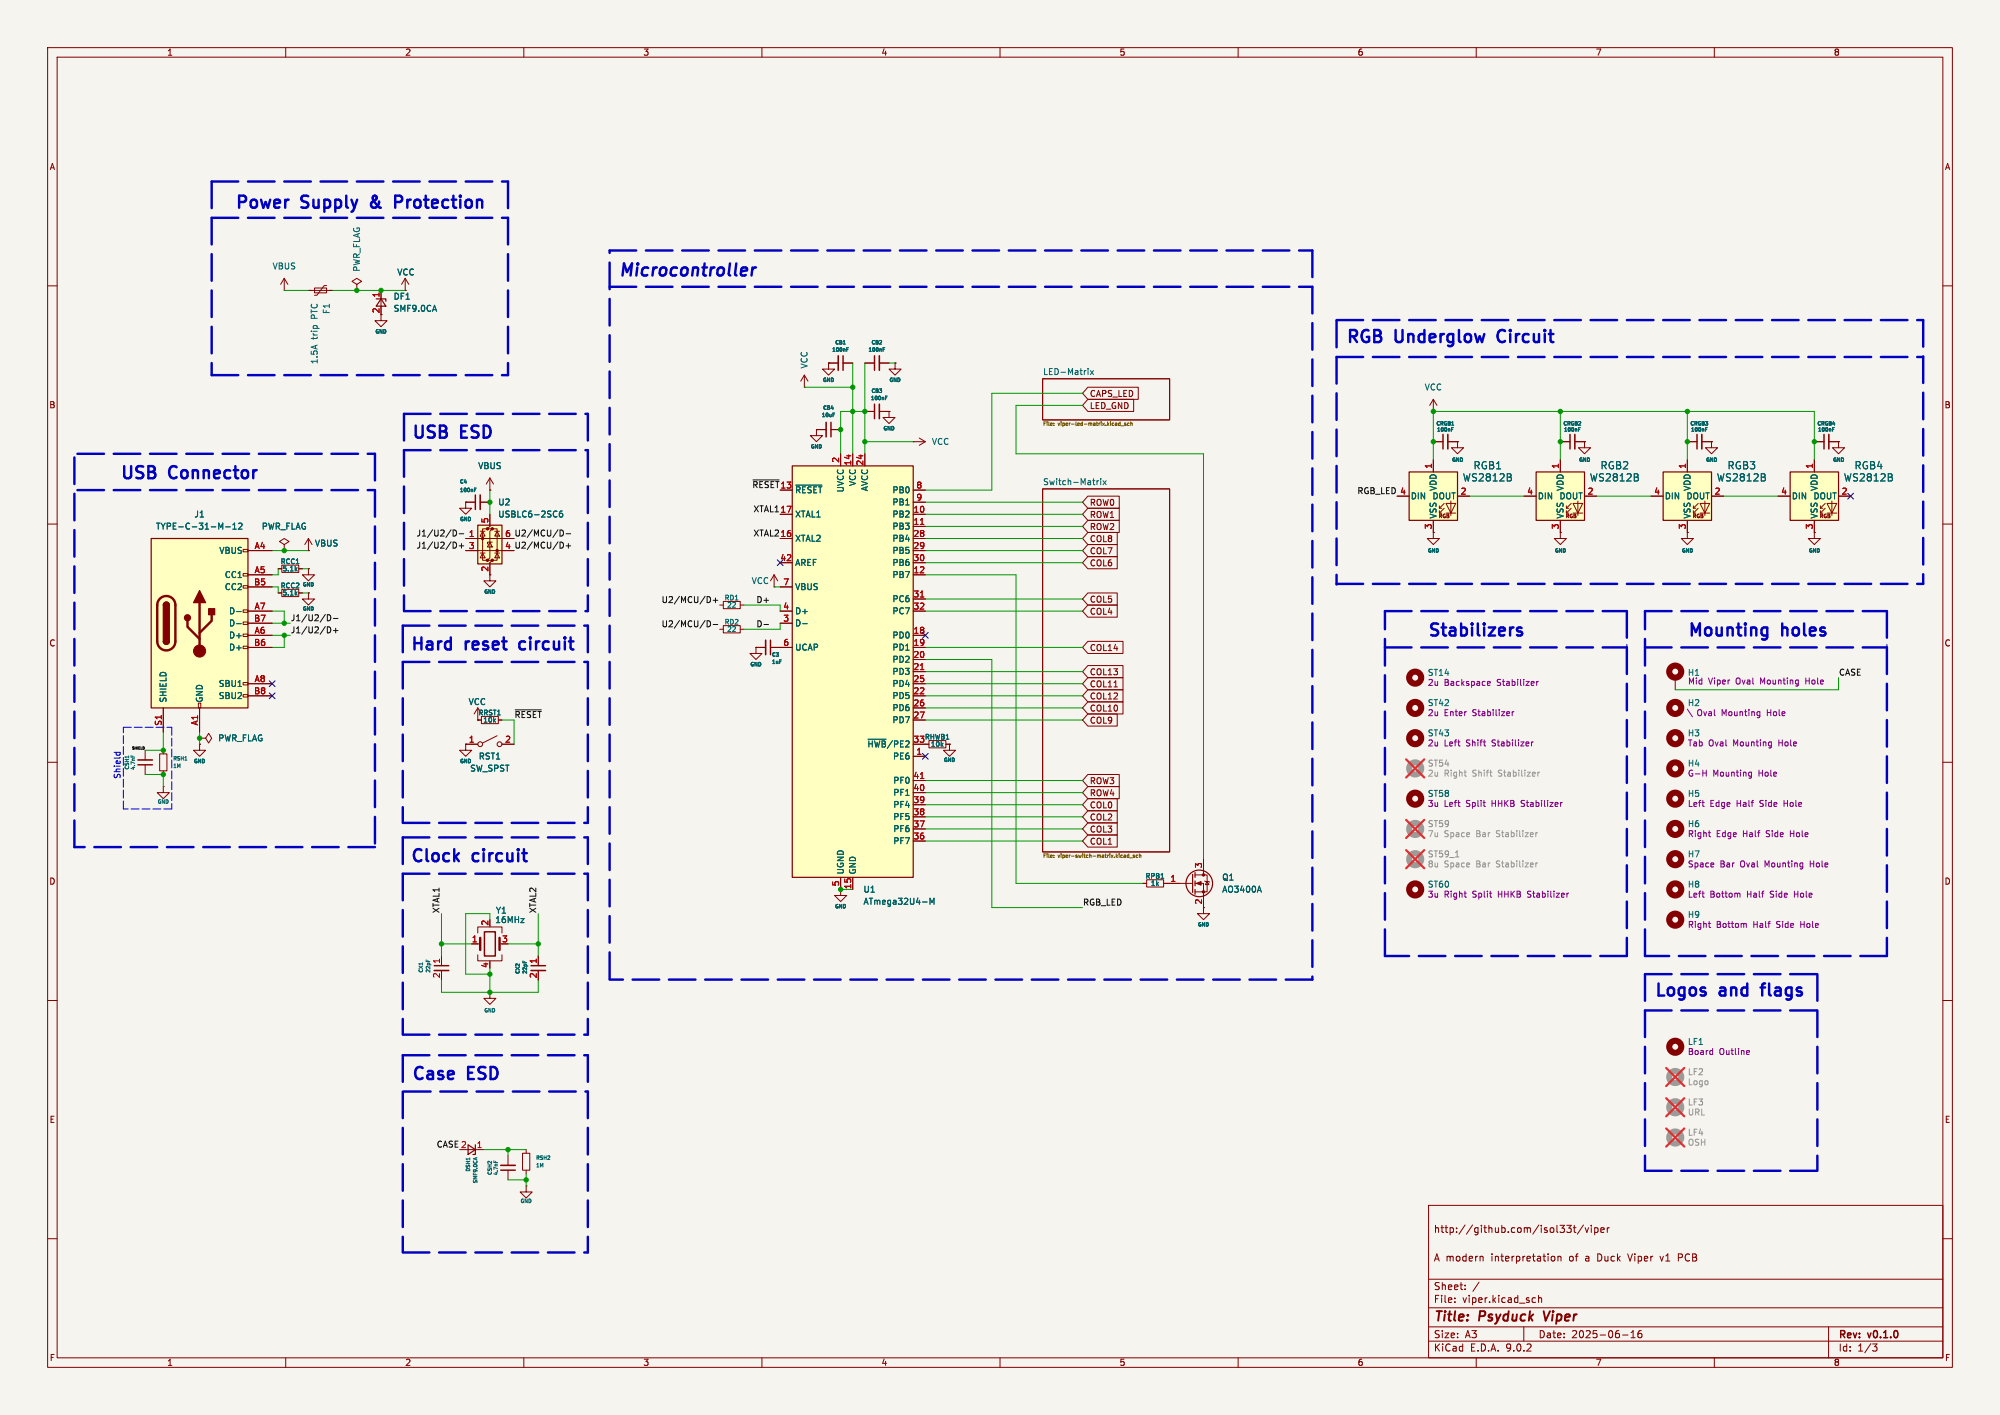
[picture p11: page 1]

5 VCC 14 GND 15 AVCC 24 PB0 8 PB1 9 PB2 10 PB3 11 PB4 28 PB5 29 PB6 30 PB7 12 PC6 31 PC7 32 PD0 18 PD1 19 PD2 20 PD3 21 PD4 25 PD5 22 PD6 26 PD7 27 ~{HWB}/PE233 PE6 1 PF0 41 PF1 40 PF4 39 PF5 38 PF6 37 PF7 36 U1ATmega32U4-M

5 VCC 14 GND 15 AVCC 24 PB0 8 PB1 9 PB2 10 PB3 11 PB4 28 PB5 29 PB6 30 PB7 12 PC6 31 PC7 32 PD0 18 PD1 19 PD2 20 PD3 21 PD4 25 PD5 22 PD6 26 PD7 27 ~{HWB}/PE233 PE6 1 PF0 41 PF1 40 PF4 39 PF5 38 PF6 37 PF7 36 RHWB1

Left Bottom Half Side Hole H1 Mid Viper Oval Mounting Hole RD1

3u Left Split HHKB Stabilizer ST14

H4 G-H Mounting Hole H2
\ Oval Mounting Hole H3 Tab Oval Mounting Hole H5

Left Edge Half Side Hole

1 2CX2 22pF GND H6 Right Edge Half Side Hole H9 Right Bottom Half Side Hole H7Space Bar Oval Mounting Hole

File: viper-switch-matrix.kicad_sch

3u Right Split HHKB Stabilizer

http://github.com/isol33t/viper

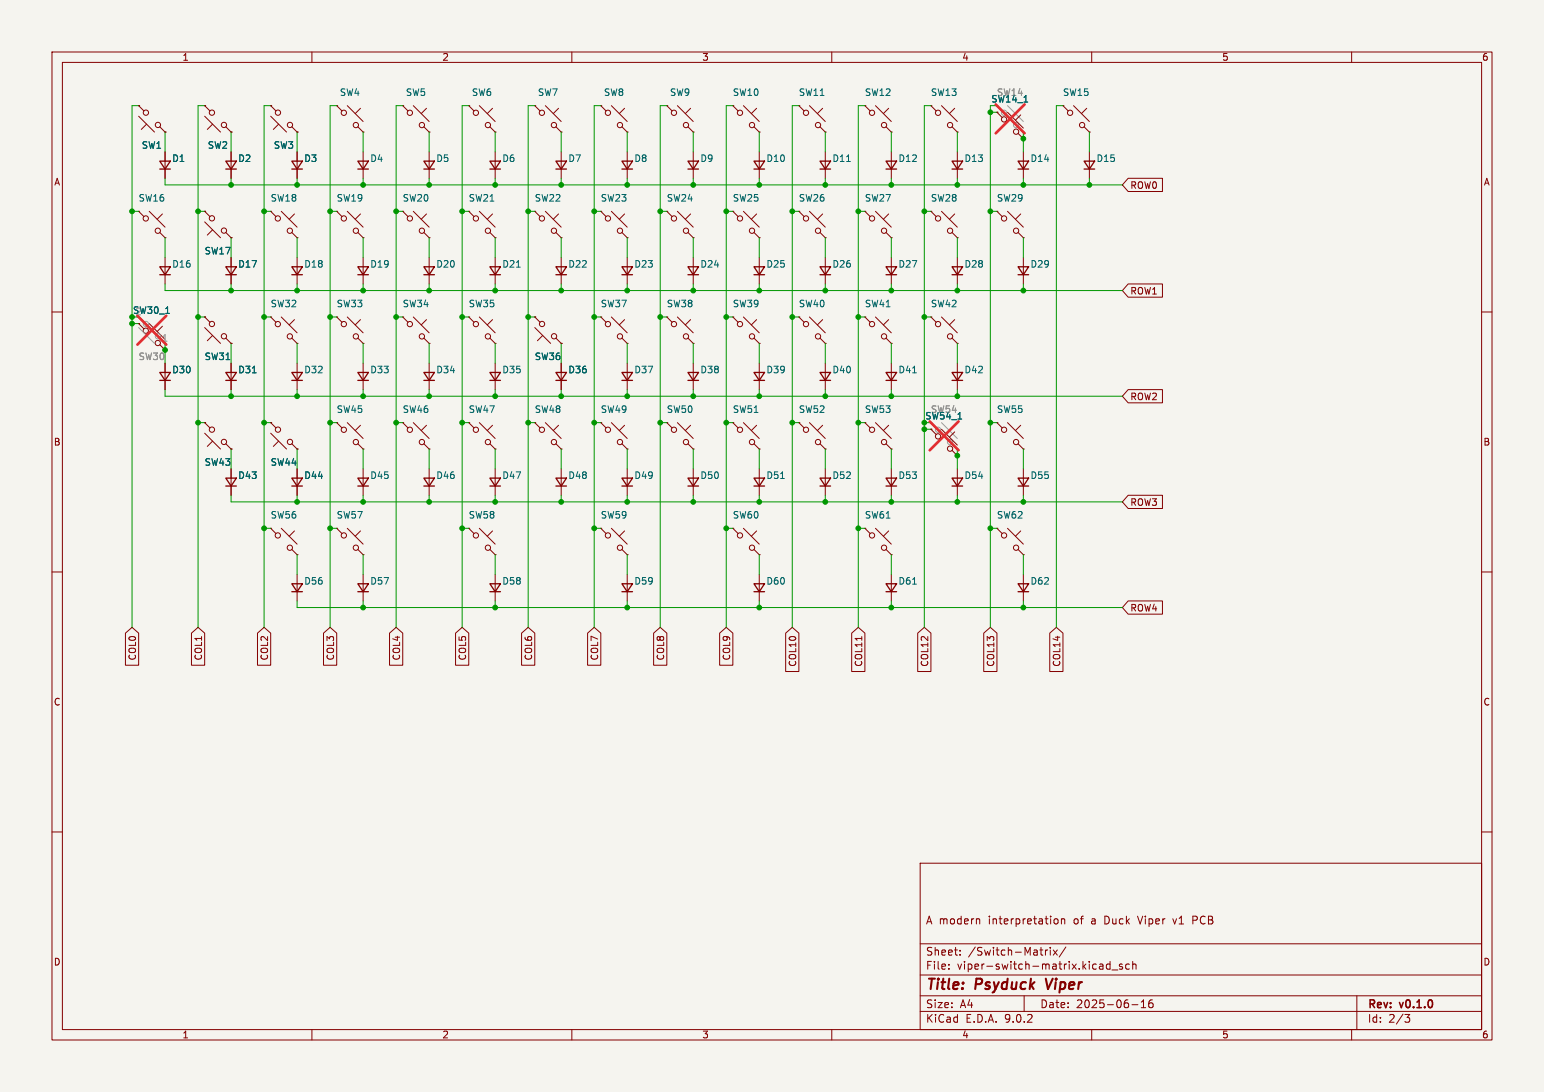
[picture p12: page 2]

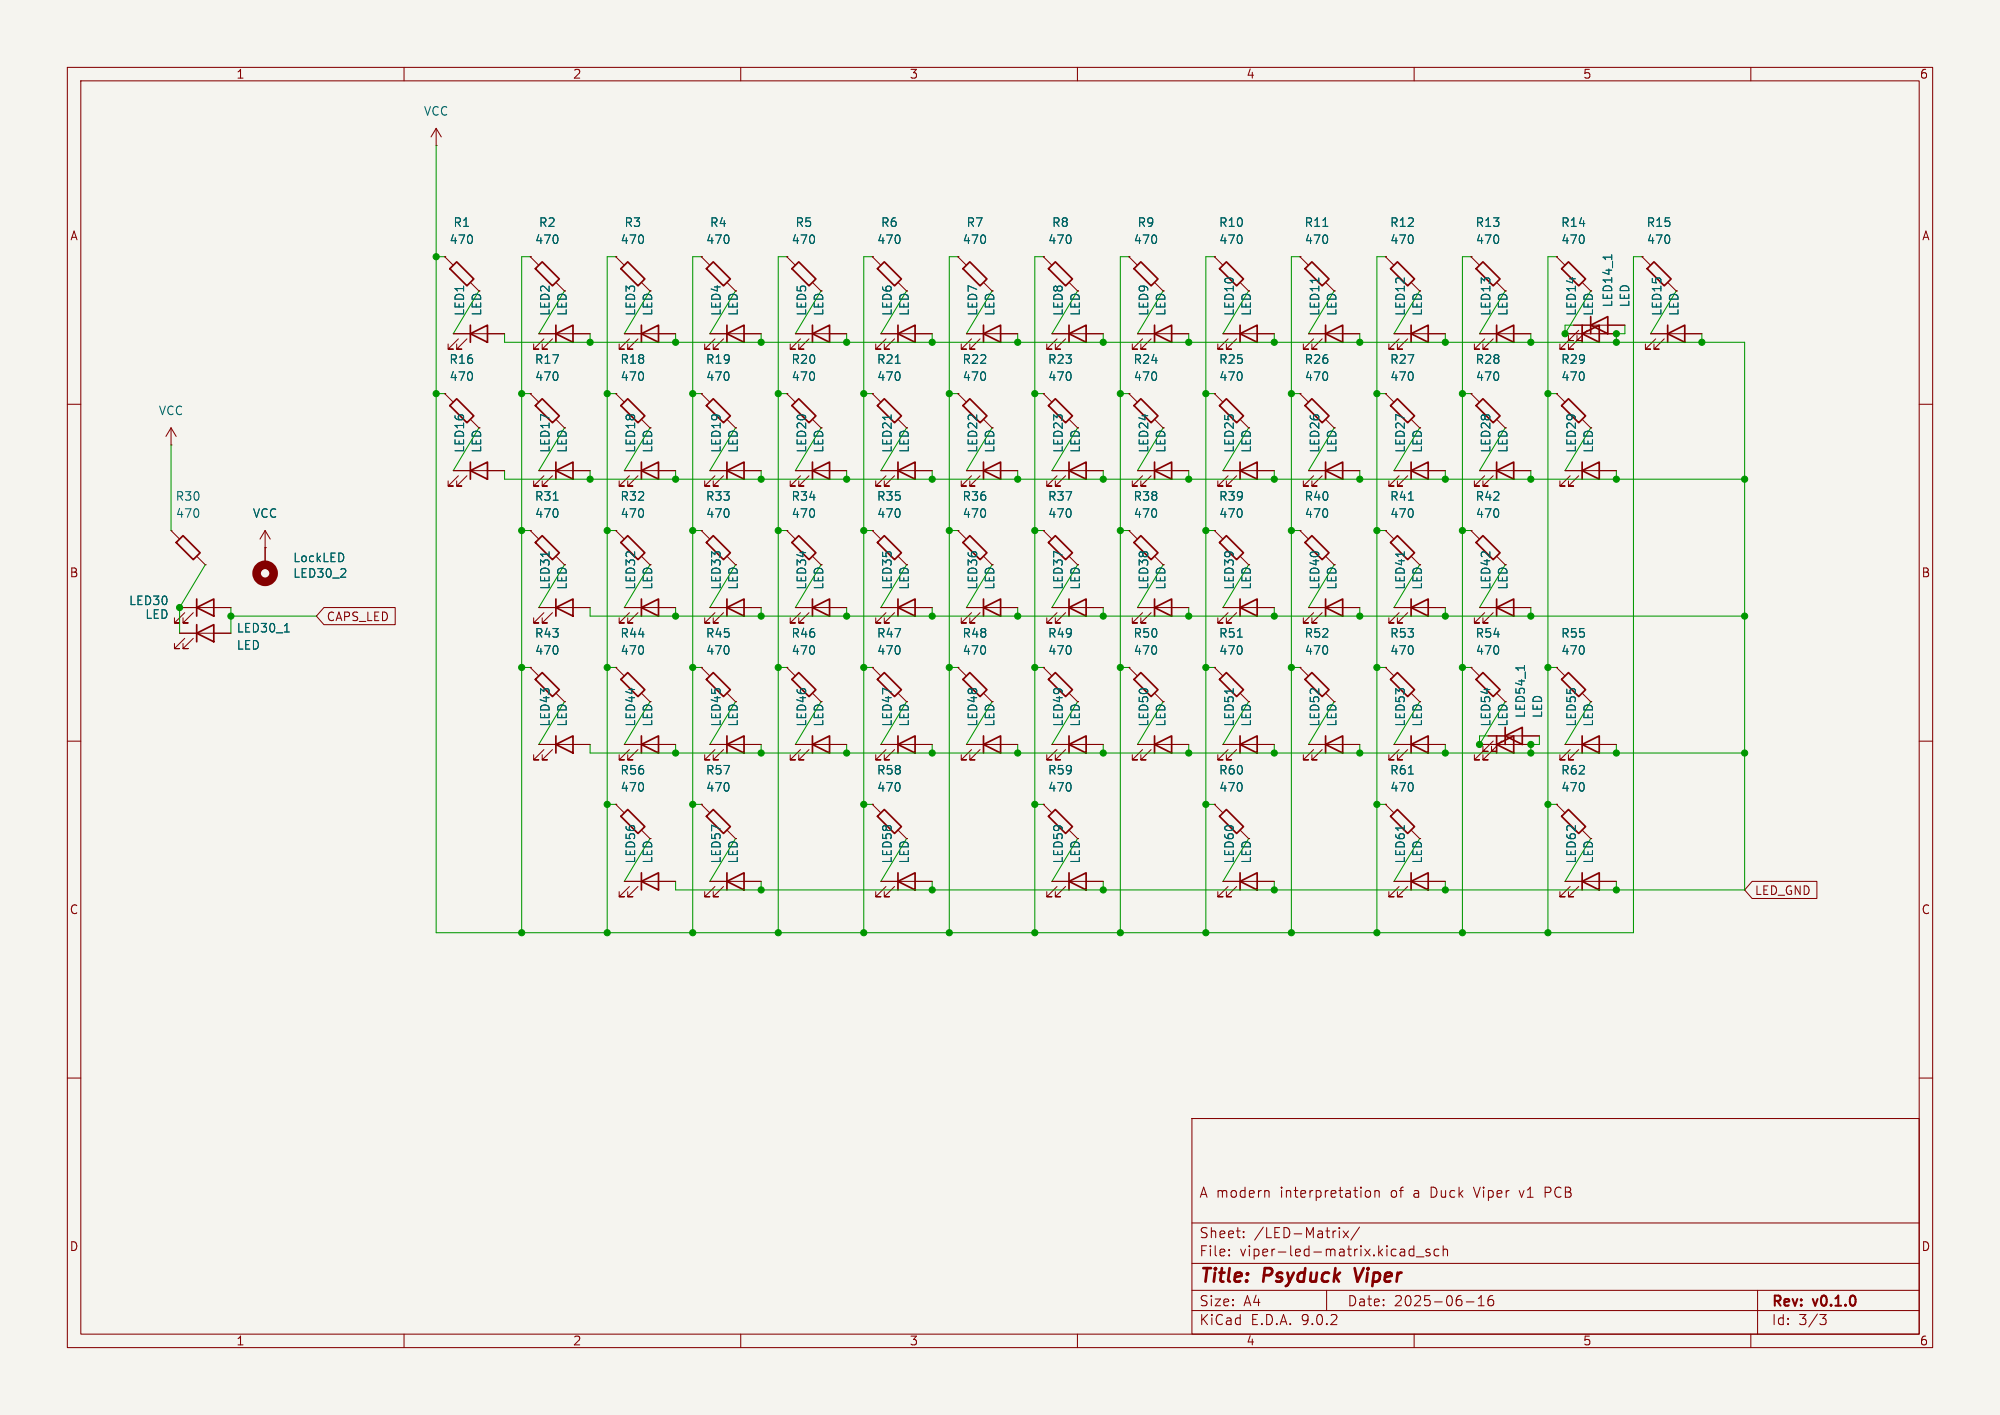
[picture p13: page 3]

470 LED50 LED LED38 LED LED57 LED LED17 LED

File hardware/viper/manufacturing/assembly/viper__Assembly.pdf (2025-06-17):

A

A

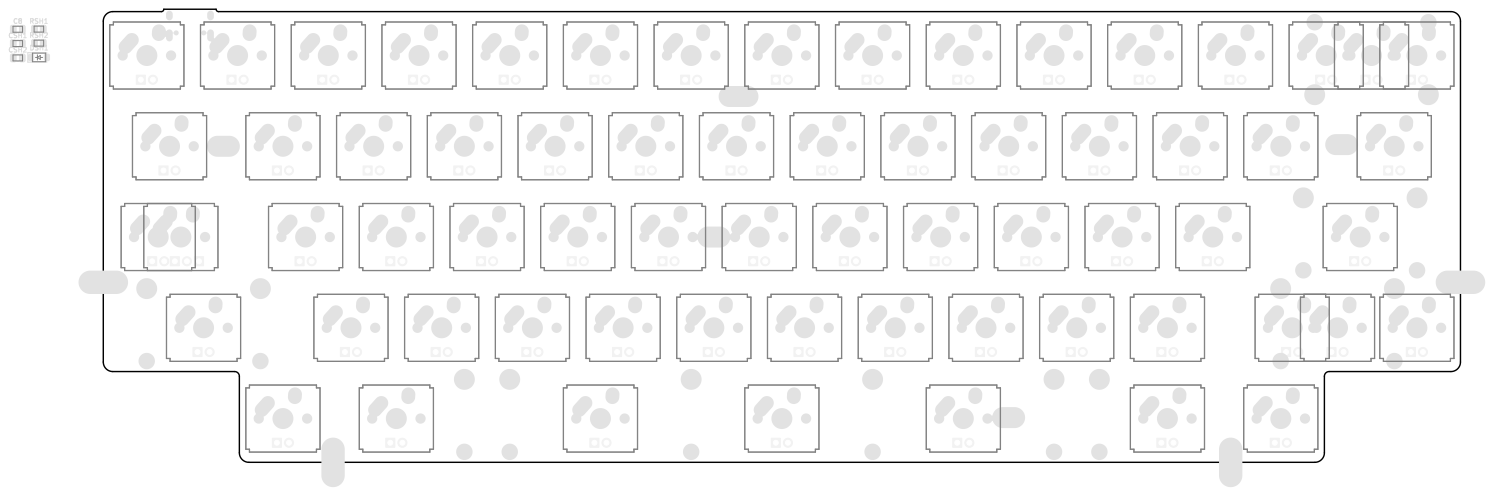
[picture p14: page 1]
CSH2 DSH1 CSH1 RSH2 C8 RSH1 1; F Date: KiCad; E.D.A. 9.0.2 Size: A3; Rev:; Id: /1 Title: File: viper.kicad_pcb Sheet:; FABRICATION_TOP; Board2Pdf:; FABRICATION_TOP -; Page

R3 C3

A

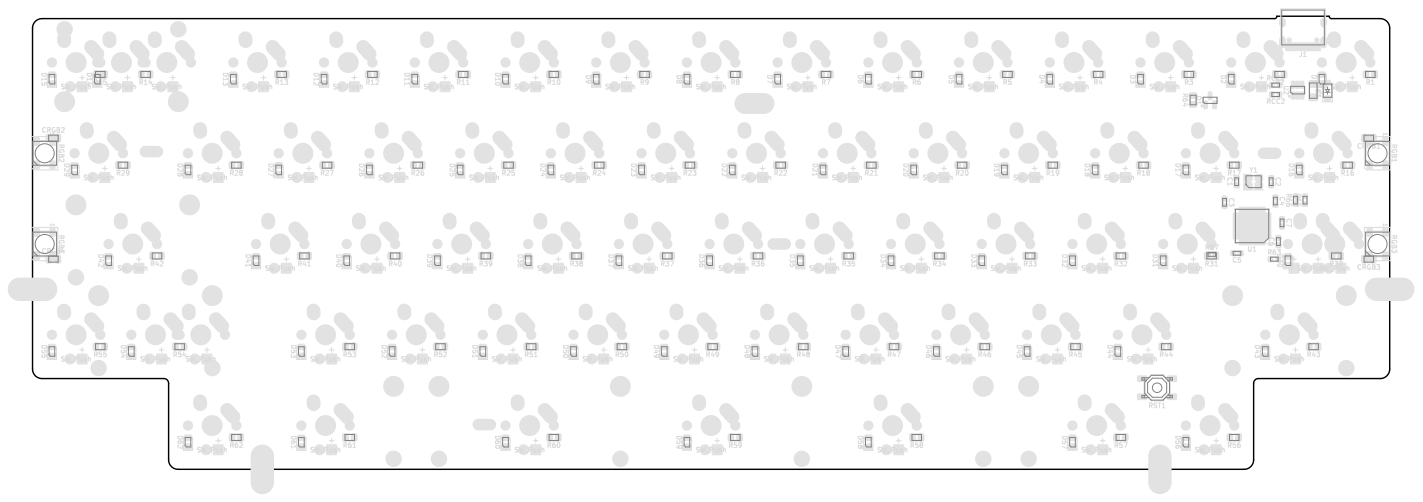
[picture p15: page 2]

A

A

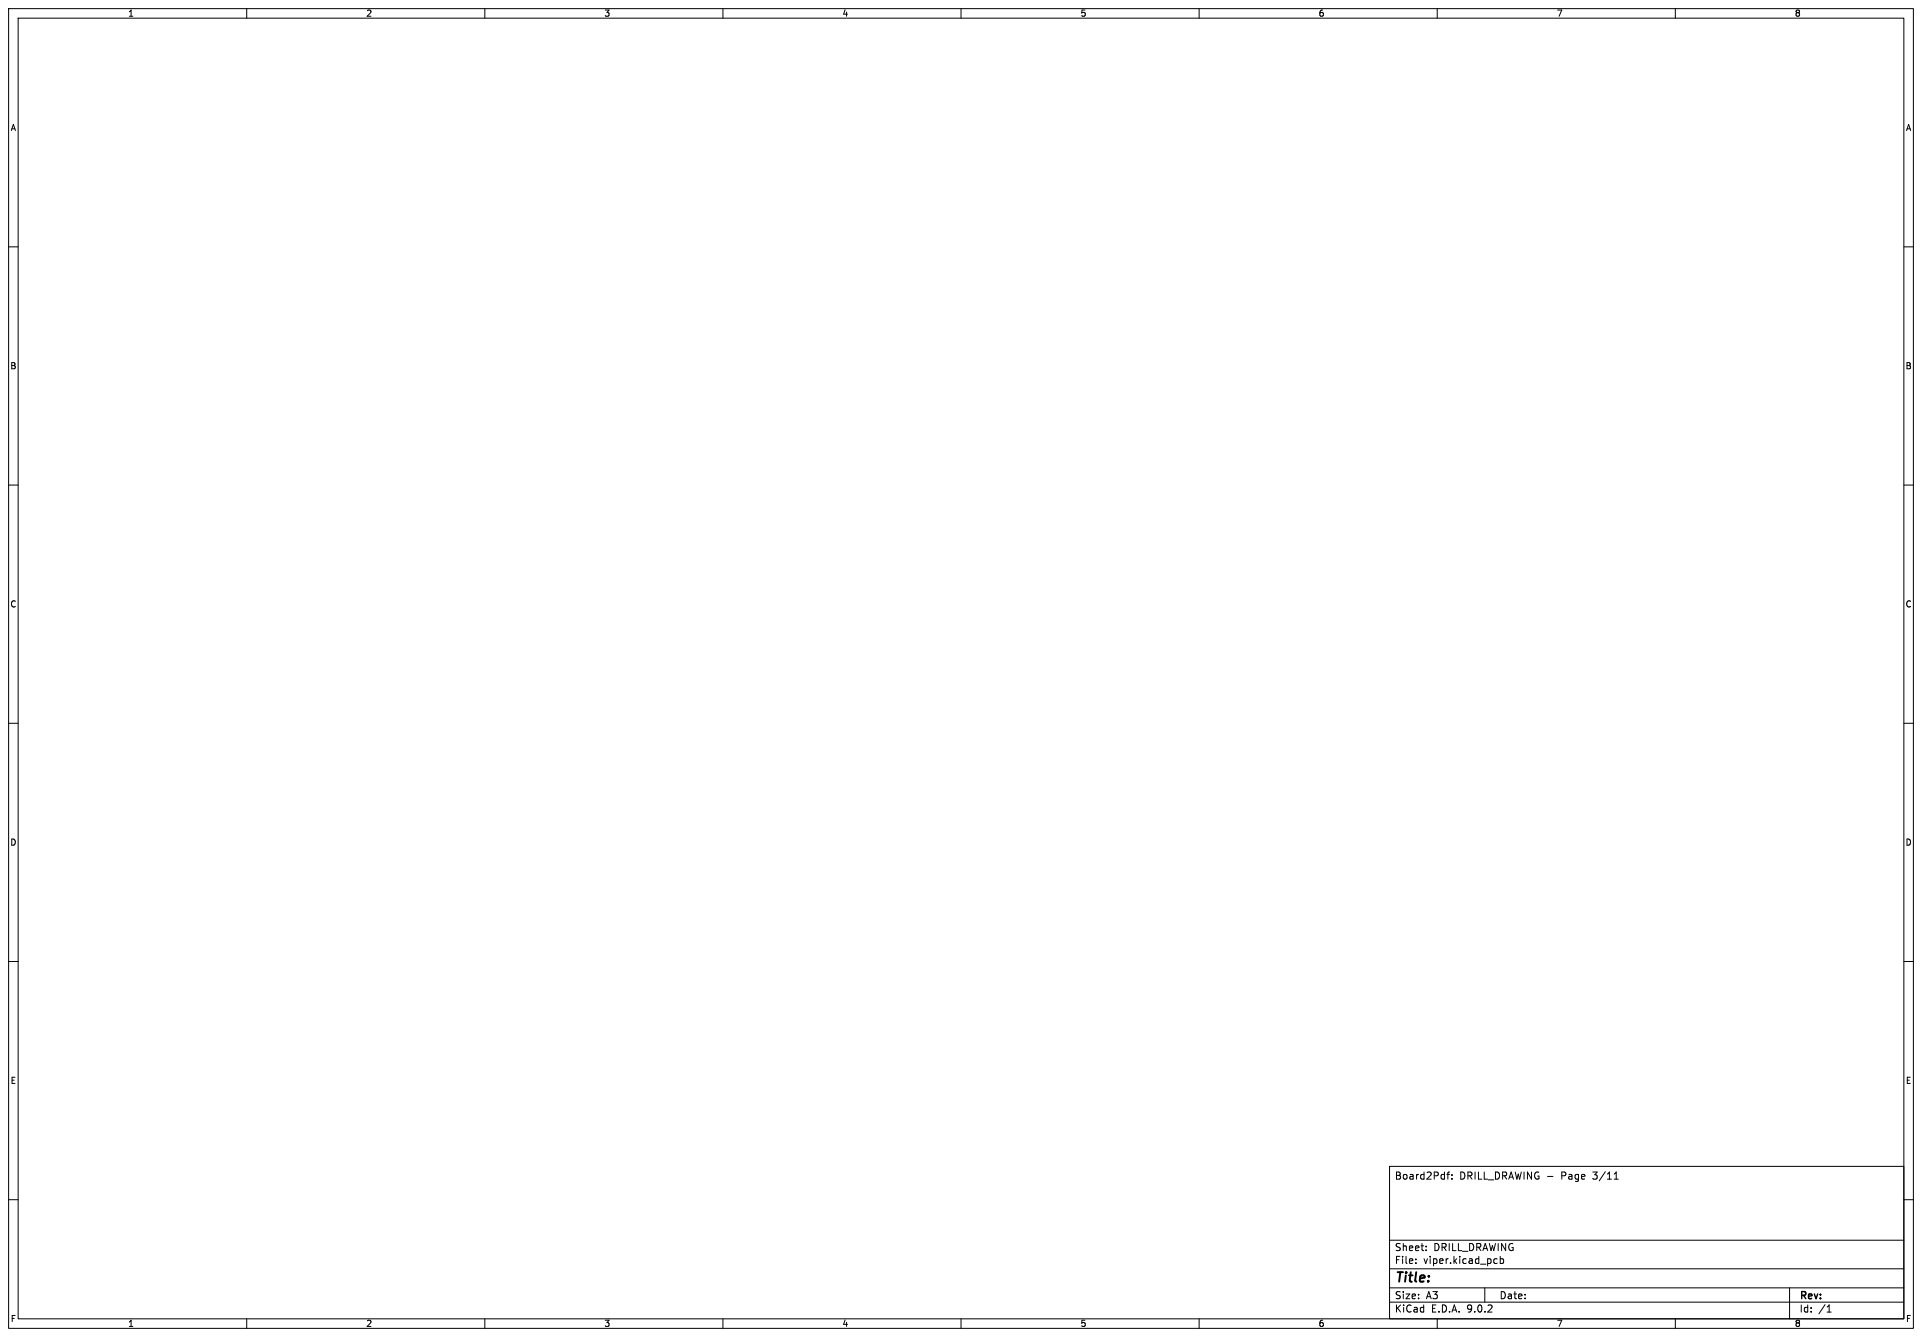
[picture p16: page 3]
Id: /1 Title: File: viper.kicad_pcb Sheet:; DRILL_DRAWING; Board2Pdf:; DRILL_DRAWING -; Page 3/11

A

A

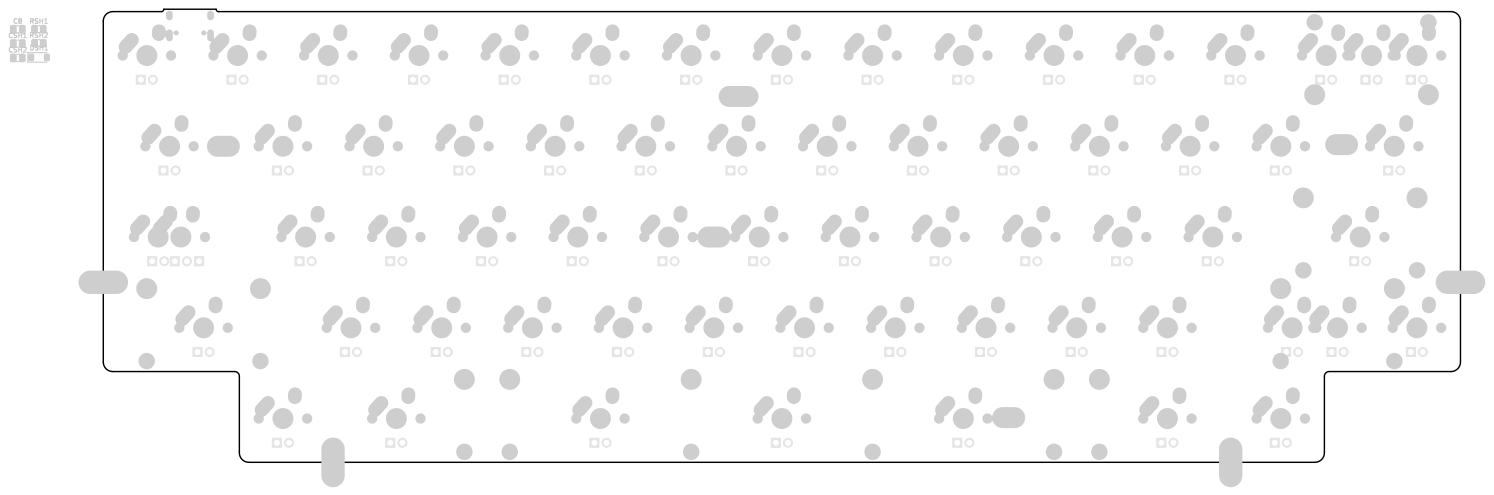
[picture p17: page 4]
CSH2 DSH1 CSH1 RSH2 C8 RSH1 1; Board2Pdf:; TESTPOINTS_TOP -; Page 4/11

Id: /1 Title: File: viper.kicad_pcb Sheet: TESTPOINTS_TOP

R3 C3

A

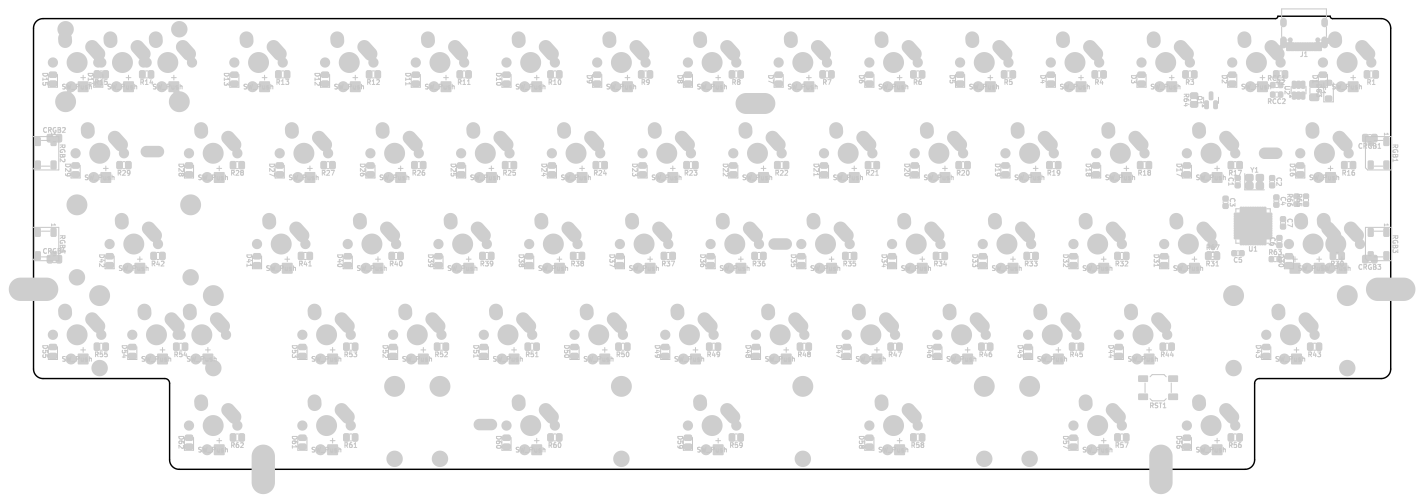
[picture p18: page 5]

A

A

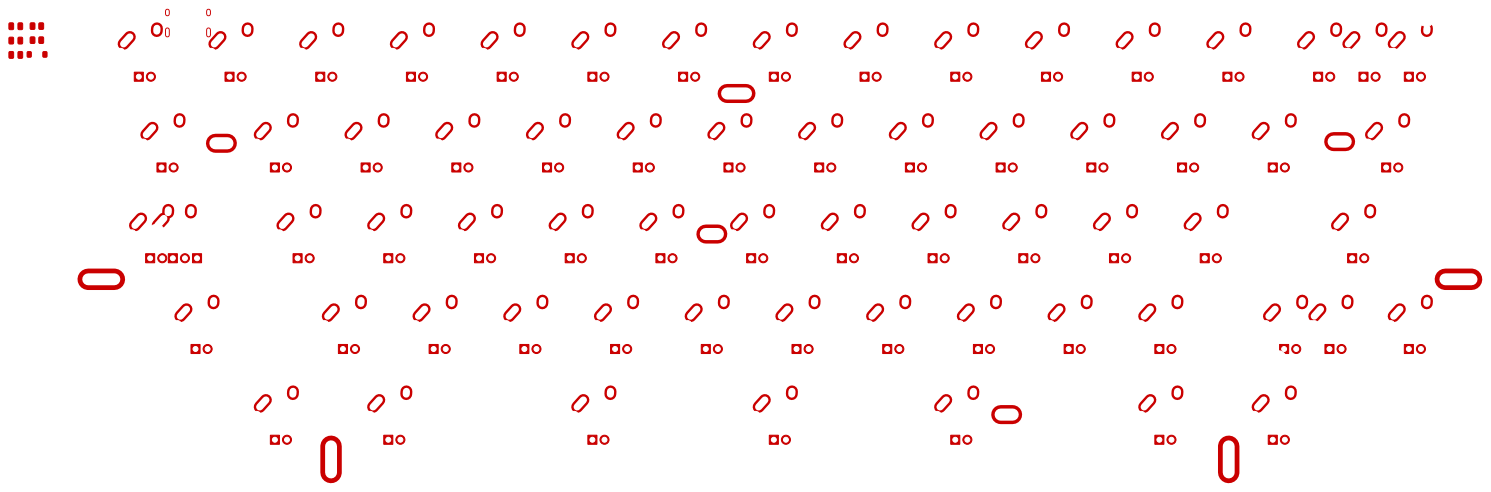
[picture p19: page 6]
Id: /1 Title: File: viper.kicad_pcb Sheet:; L1 Board2Pdf:; Page 6/11

A

A

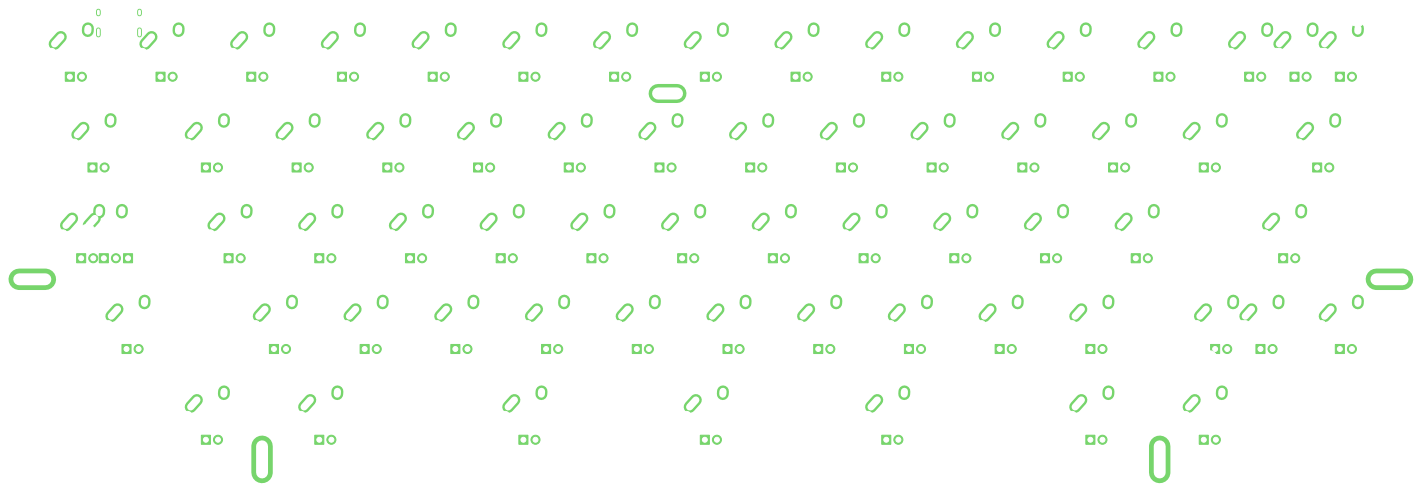
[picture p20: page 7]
Id: /1 Title: File: viper.kicad_pcb Sheet:; L2 Board2Pdf:; Page 7/11

A

A

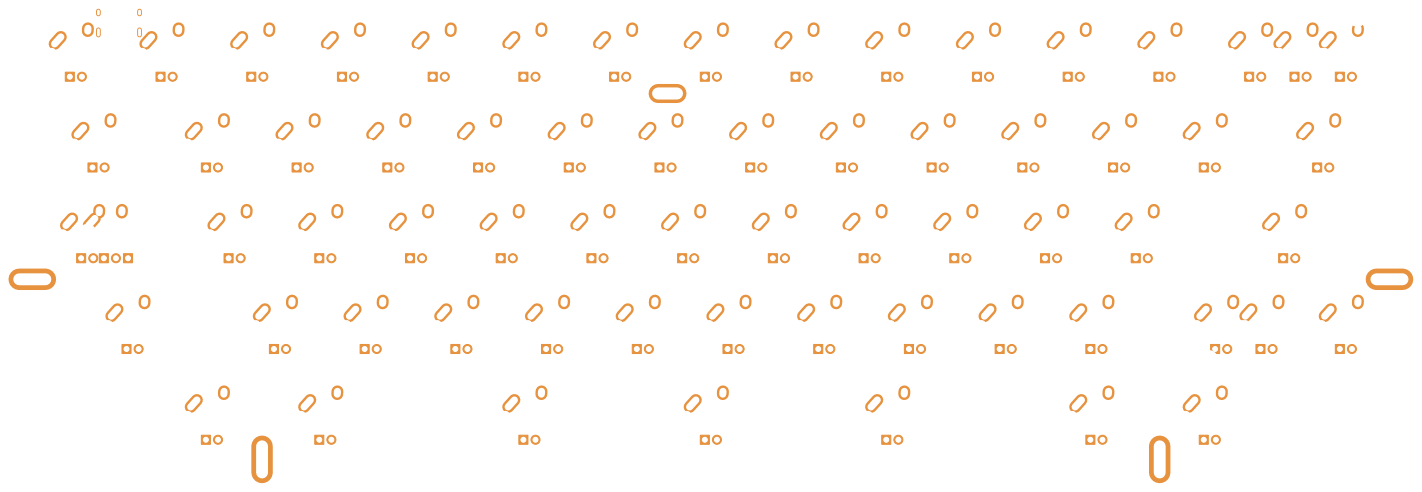
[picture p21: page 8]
Id: /1 Title: File: viper.kicad_pcb Sheet:; L3 Board2Pdf:; Page 8/11

A

A

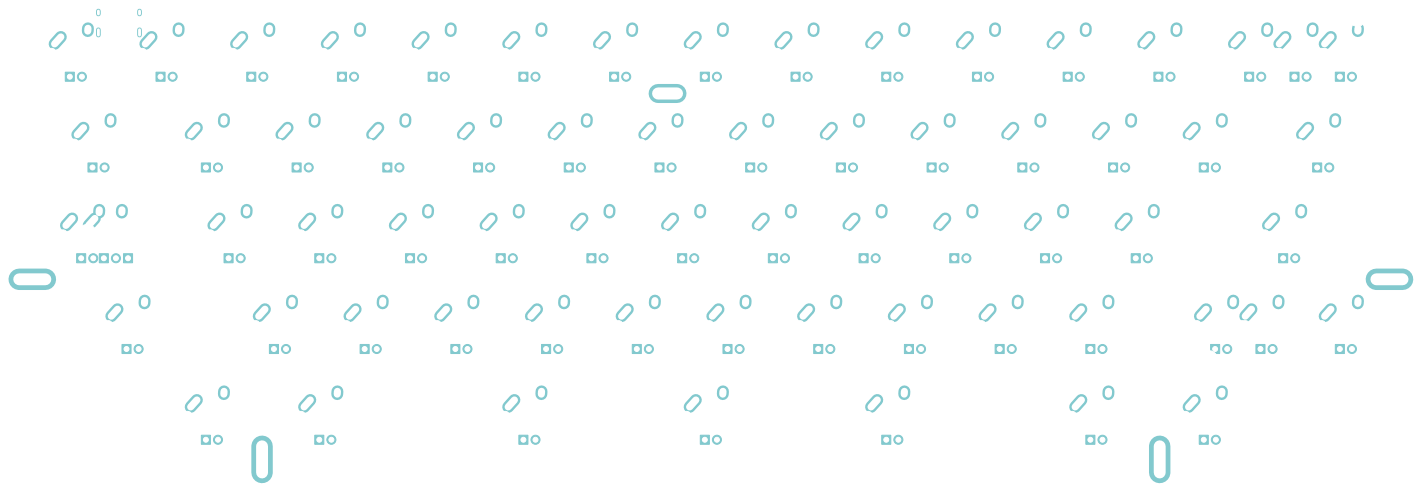
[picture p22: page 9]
Id: /1 Title: File: viper.kicad_pcb Sheet:; L4 Board2Pdf:; Page 9/11

A

A

Id: /1 Title: File: viper.kicad_pcb Sheet:; L5 Board2Pdf:; Page

A

A

Id: /1 Title: File: viper.kicad_pcb Sheet:; L6 Board2Pdf:; Page

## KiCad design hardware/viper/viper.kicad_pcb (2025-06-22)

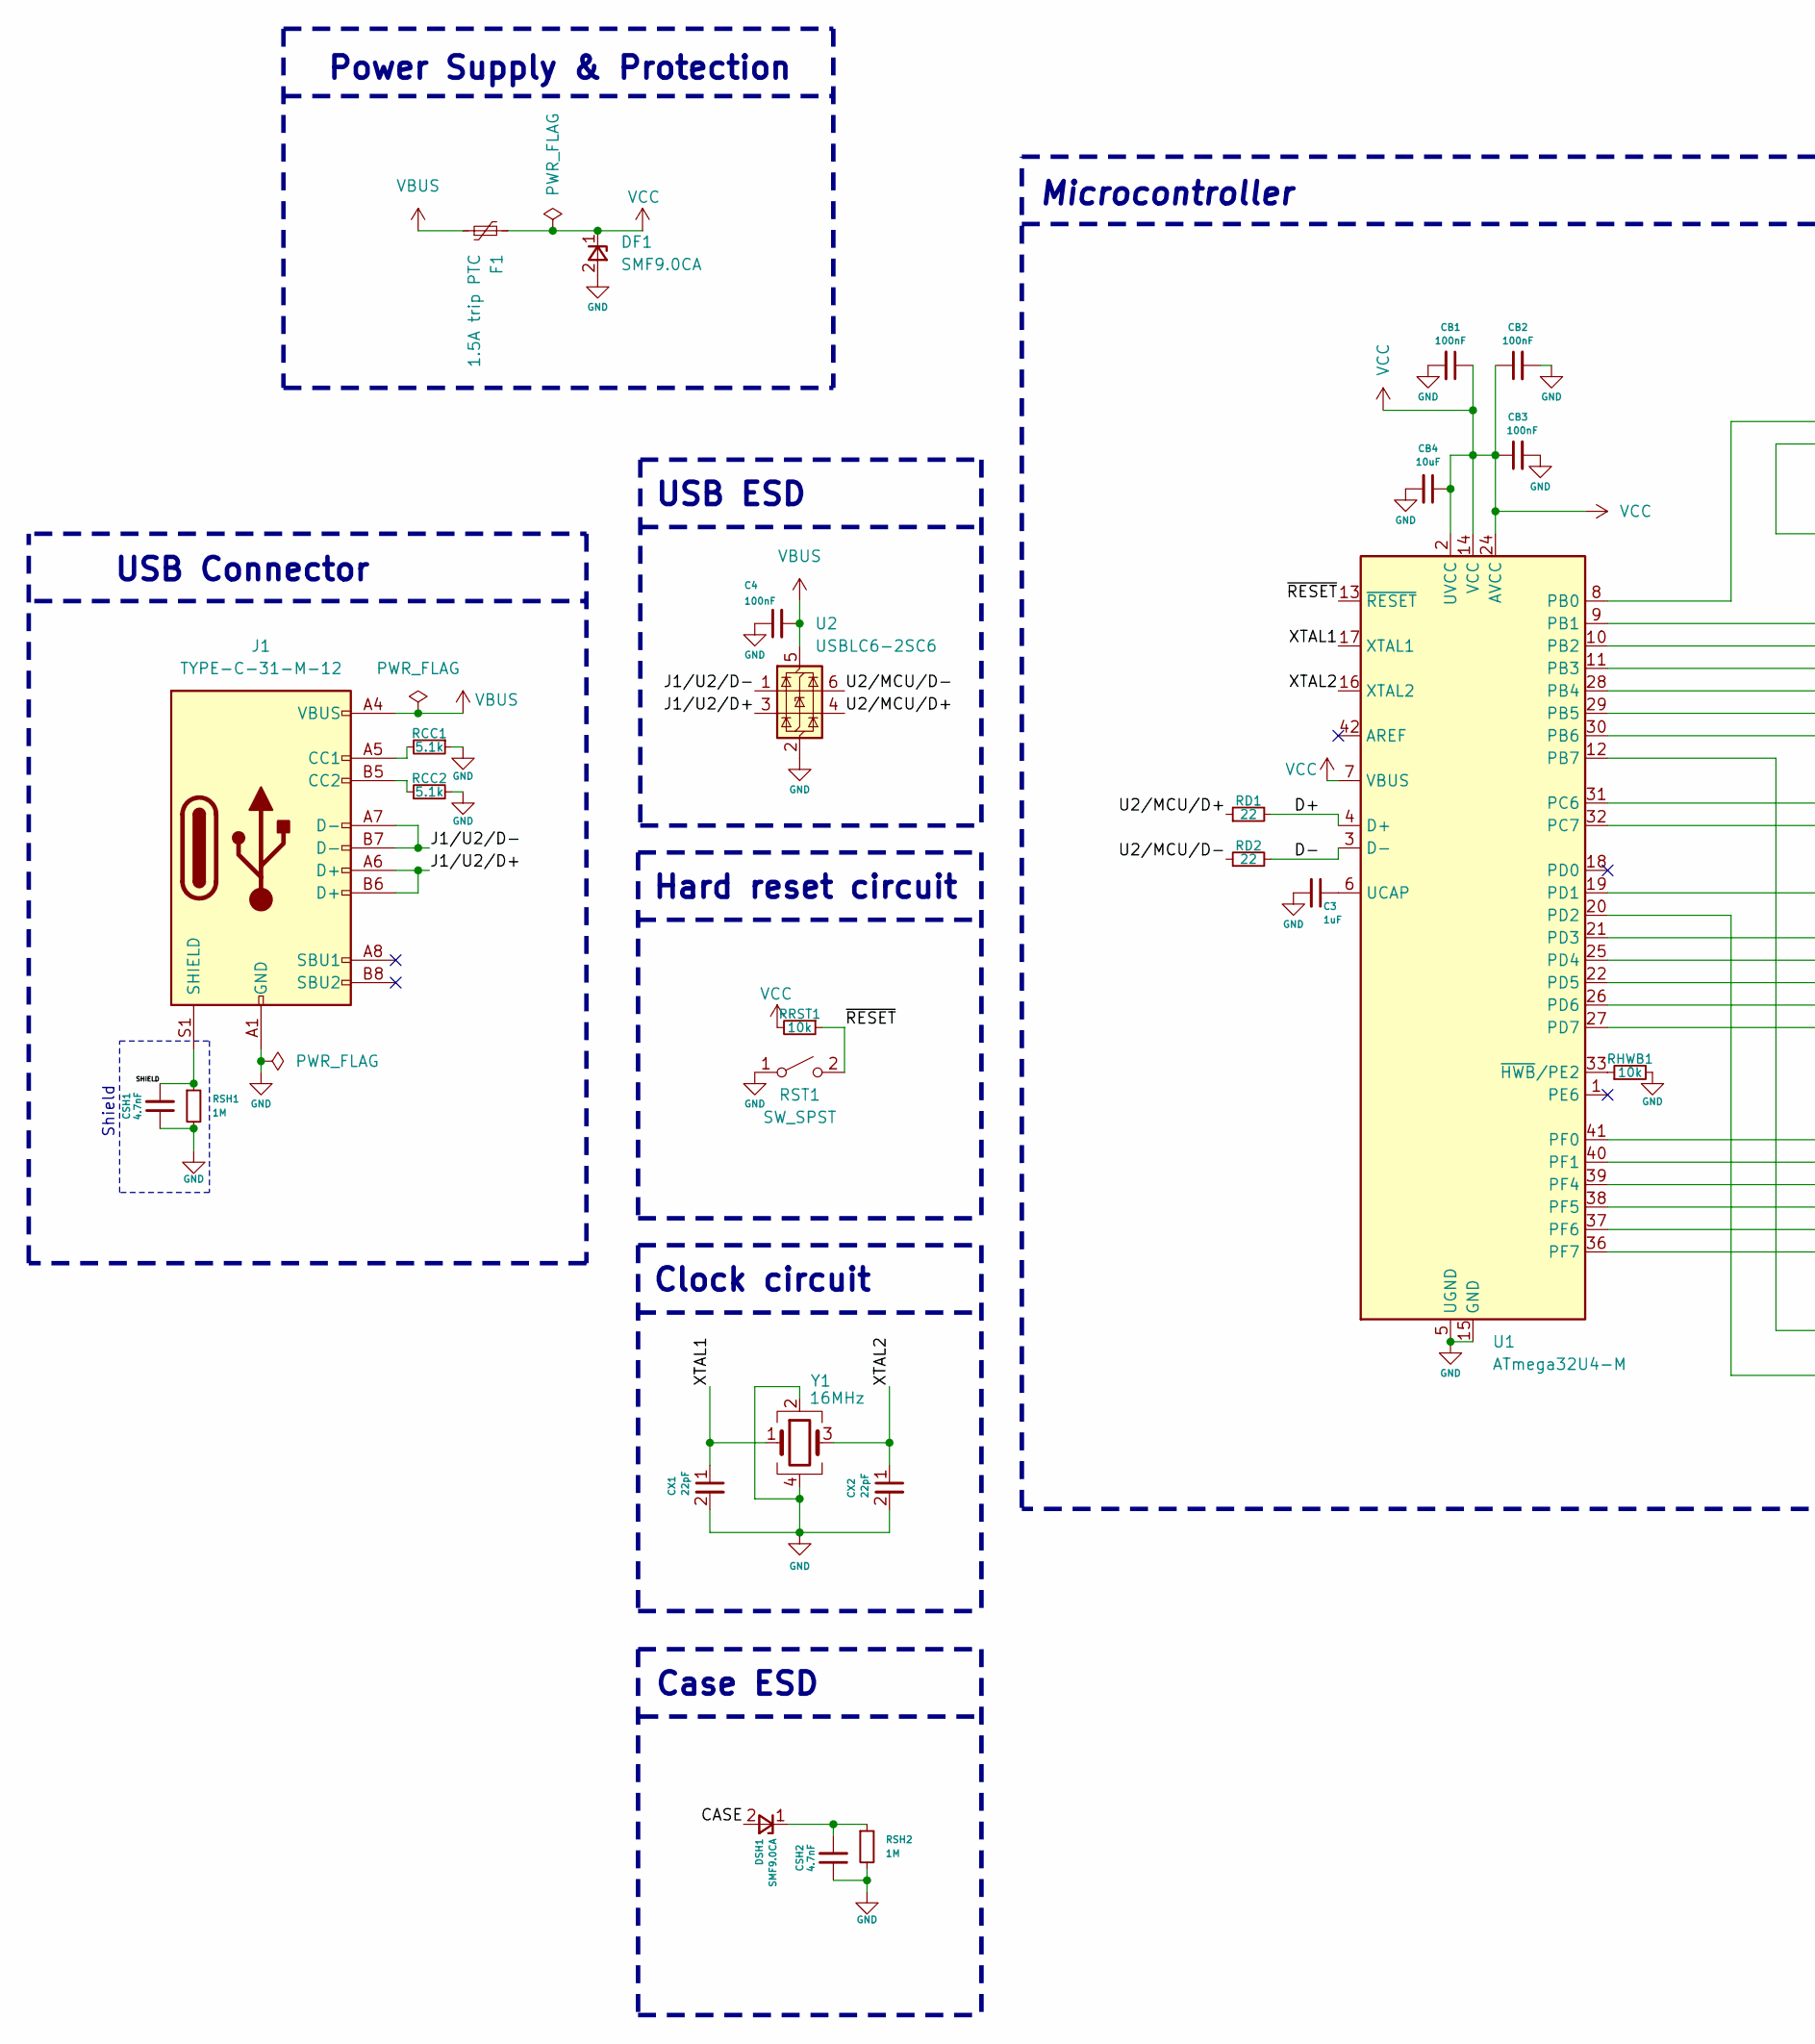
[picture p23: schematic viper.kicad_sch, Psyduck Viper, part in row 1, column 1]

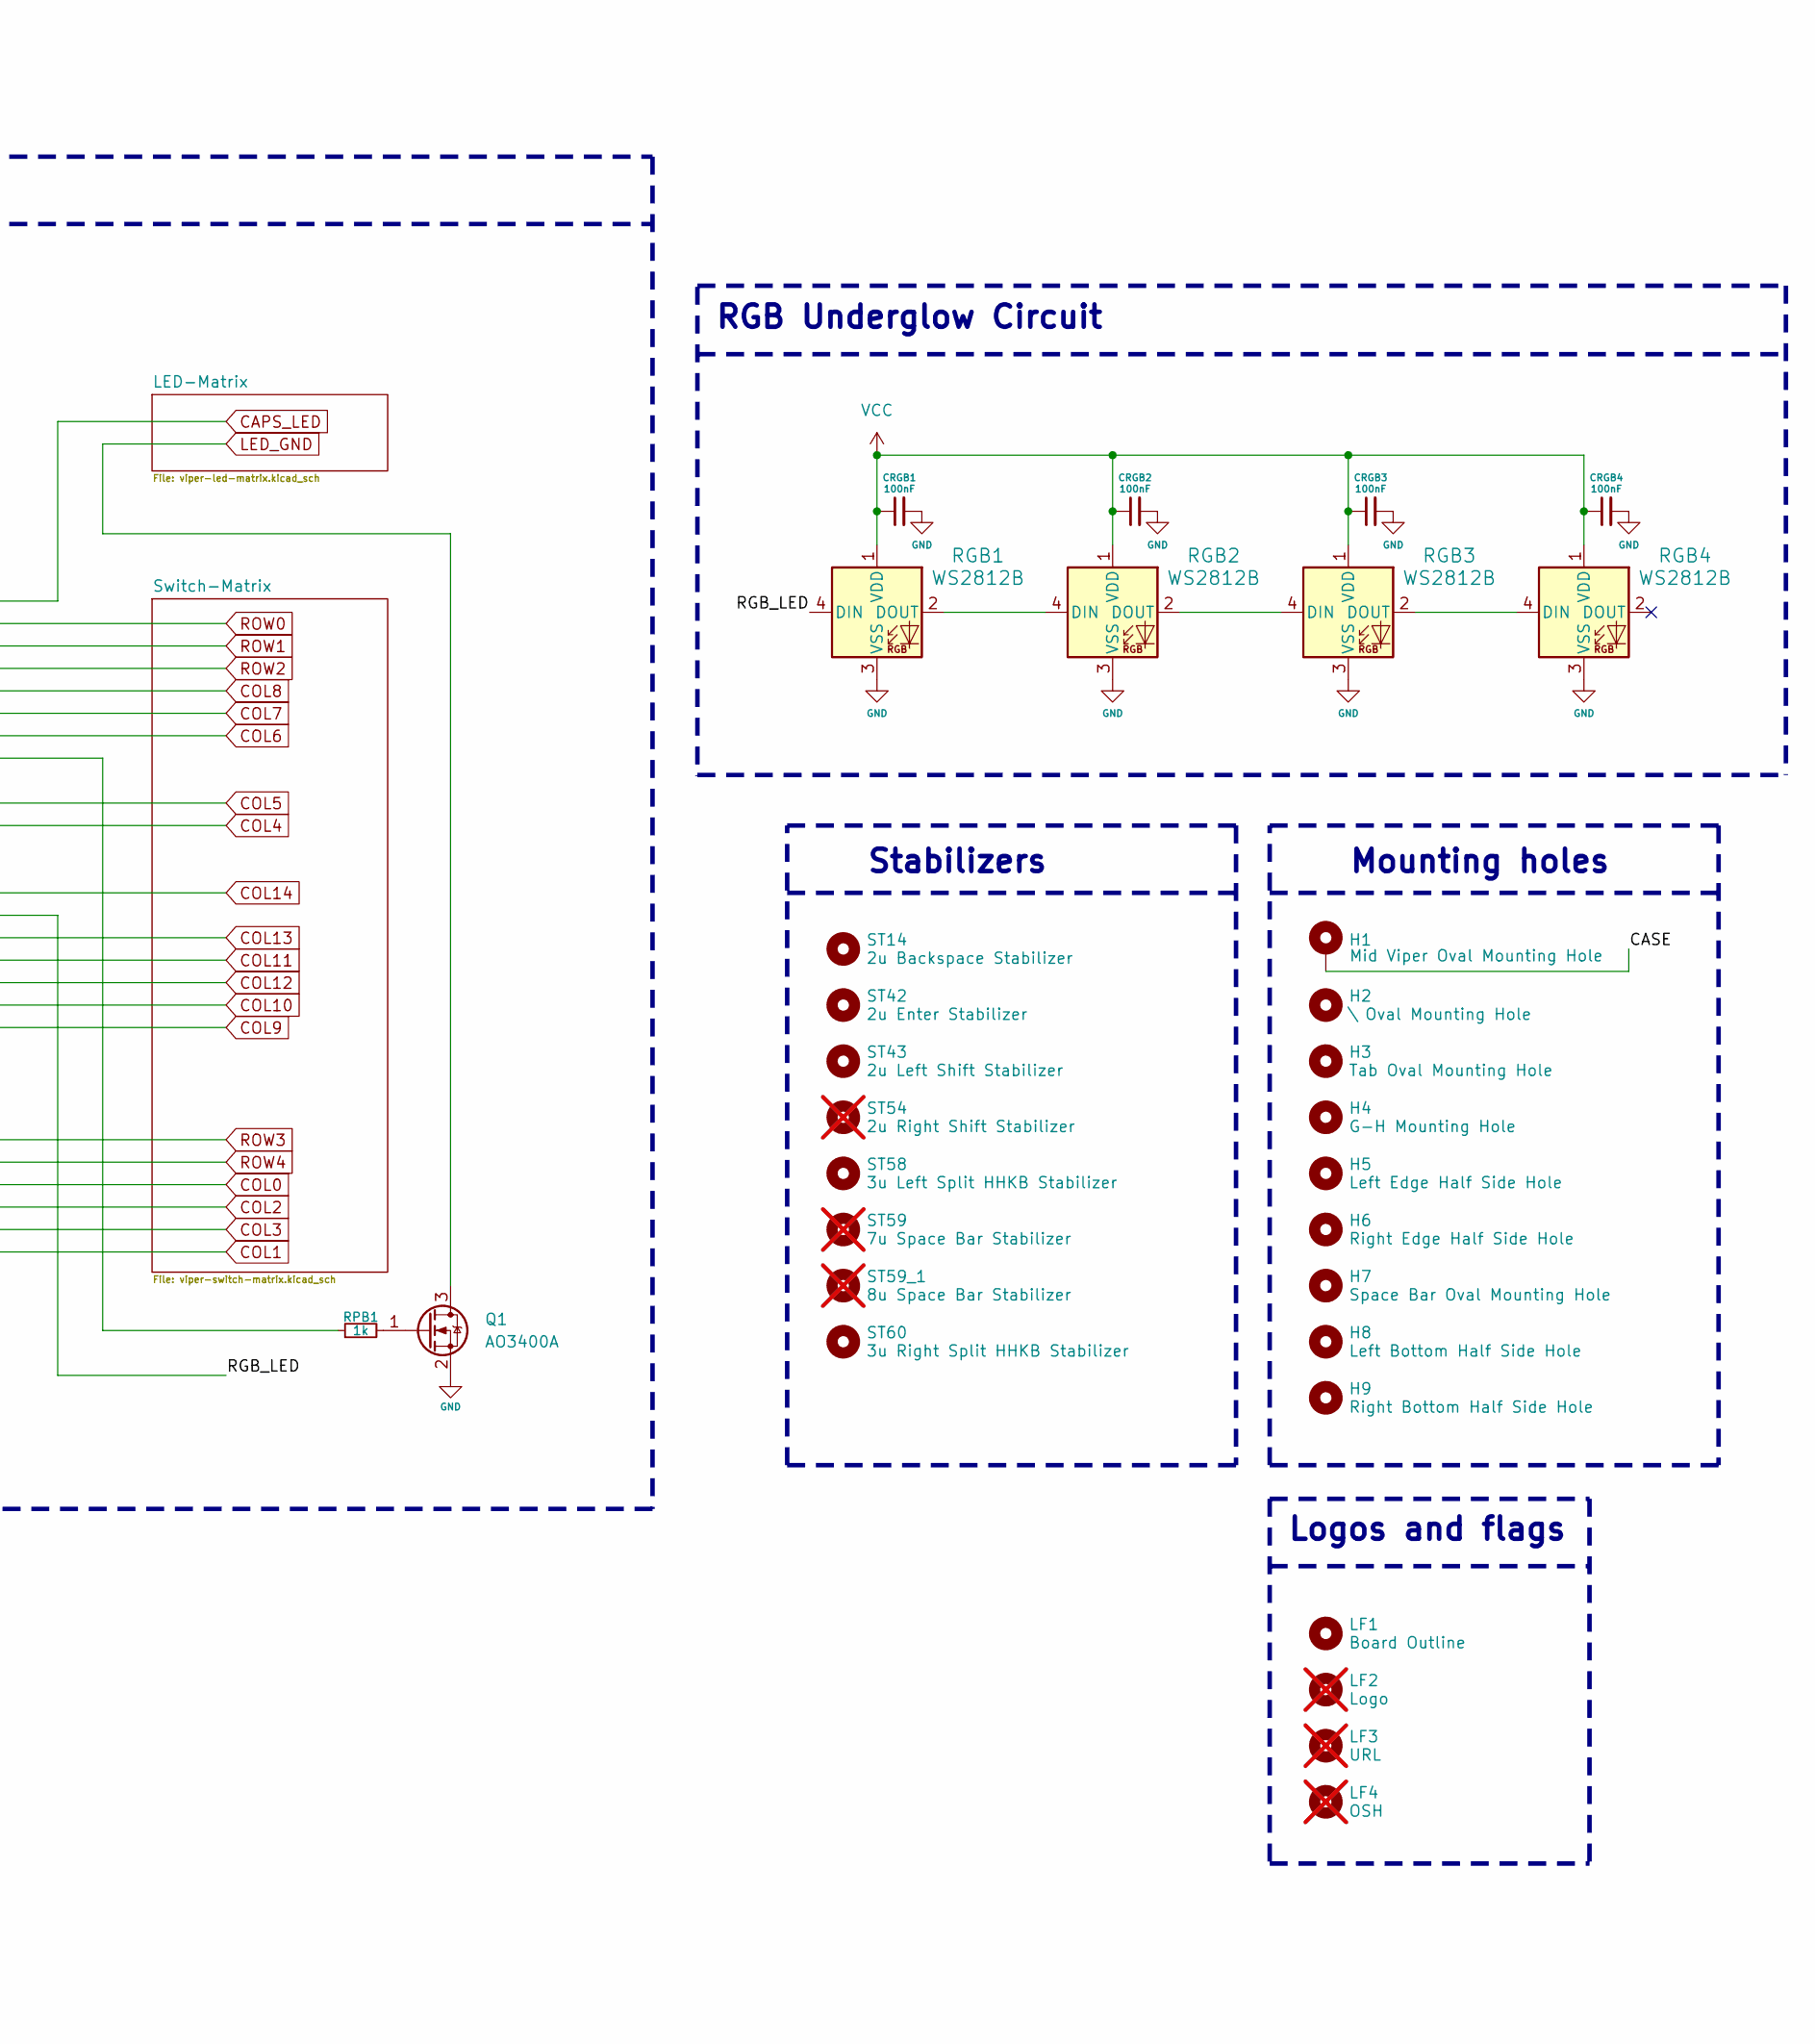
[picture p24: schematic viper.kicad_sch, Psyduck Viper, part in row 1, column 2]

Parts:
C3: 1uF; C_0603_1608Metric; LCSC C29936
C4: 100nF; C_0805_2012Metric; LCSC C36911366
CB1, CB2, CB3: 100nF; C_0603_1608Metric; LCSC C1591
CB4: 10uF; C_0603_1608Metric; LCSC C96446
CRGB1, CRGB2, CRGB3, CRGB4: 100nF; C_0805_2012Metric; LCSC C36911366
CSH1, CSH2: 4.7nF; C_0805_2012Metric; LCSC C77063
CX1, CX2: 22pF; C_0603_1608Metric; LCSC C1653
DF1: SMF9.0CA; D_SOD-123; LCSC C19077504
DSH1: SMF9.0CA; D_SOD-123; LCSC C19077504
F1: 1.5A trip PTC; Fuse_1206_3216Metric; LCSC C2153712
H1: Mounting_Hole_Oval_2.5x8mm
H2, H3, H4, H7: MoutingHole_Oval_BackOnly_7mm_5.0x2.5mm
H5, H6, H8, H9: halfSideHole
J1: TYPE-C-31-M-12; USB_C_Receptacle_HRO_TYPE-C-31-M-12; LCSC C165948
LF1: viper_outline
LF2, LF3, LF4: not fitted
Q1: AO3400A; SOT-23; LCSC C7603192
RCC1, RCC2: 5.1k; R_0603_1608Metric; LCSC C23186
RD1, RD2: 22; R_0603_1608Metric; LCSC C23345
RGB1, RGB3, RGB4: WS2812B; LED_WS2812B-Mini_PLCC4_3.5x3.5mm; LCSC C5349955
RGB2: WS2812B; LED_WS2812B-Mini_PLCC4_3.5x3.5mm; LCSC C527089
RHWB1: 10k; R_0603_1608Metric; LCSC C25804
RPB1: 1k; R_0805_2012Metric; LCSC C17513
RRST1: 10k; R_0603_1608Metric; LCSC C25804
RSH1, RSH2: 1M; R_0805_2012Metric
RST1: SW_SPST; SW_SPST_TL3342; LCSC C92584
ST14, ST42, ST43: Stabilizer_Cherry_MX_2.00u
ST54: Stabilizer_Cherry_MX_2.00u; not fitted
ST58, ST60: Stabilizer_Cherry_MX_3.00u
ST59: Stabilizer_Cherry_MX_7.00u; not fitted
ST59_1: Stabilizer_Cherry_MX_8.00u; not fitted
U1: ATmega32U4-M; QFN-44-1EP_7x7mm_P0.5mm_EP5.2x5.2mm; LCSC C112161
U2: USBLC6-2SC6; SOT-23-6; LCSC C7519
Y1: 16MHz; Crystal_SMD_3225-4Pin_3.2x2.5mm; LCSC C255909

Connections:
/CASE: DSH1.2 (A), H1.1
/D+: RD1.2, U1.4 (D+)
/D-: RD2.2, U1.3 (D-)
/J1/U2/D+: J1.A6 (D+), J1.B6 (D+), U2.3 (I/O2)
/J1/U2/D-: J1.A7 (D-), J1.B7 (D-), U2.1 (I/O1)
/RGB_LED: RGB1.4 (DIN), U1.20 (PD2)
/SHIELD: CSH1.2, J1.S1 (SHIELD), RSH1.1
/U2/MCU/D+: RD1.1, U2.4 (I/O2)
/U2/MCU/D-: RD2.1, U2.6 (I/O1)
/XTAL1: CX1.1, U1.17 (XTAL1), Y1.1
/XTAL2: CX2.1, U1.16 (XTAL2), Y1.3
/~RESET: RRST1.1, RST1.2 (B), U1.13 (~RESET)
CAPS_LED: U1.8 (PB0); also elsewhere on the board
COL0: U1.39 (PF4); also elsewhere on the board
COL1: U1.36 (PF7); also elsewhere on the board
COL2: U1.38 (PF5); also elsewhere on the board
COL3: U1.37 (PF6); also elsewhere on the board
COL4: U1.32 (PC7); also elsewhere on the board
COL5: U1.31 (PC6); also elsewhere on the board
COL6: U1.30 (PB6); also elsewhere on the board
COL7: U1.29 (PB5); also elsewhere on the board
COL8: U1.28 (PB4); also elsewhere on the board
COL9: U1.27 (PD7); also elsewhere on the board
COL10: U1.26 (PD6); also elsewhere on the board
COL11: U1.25 (PD4); also elsewhere on the board
COL12: U1.22 (PD5); also elsewhere on the board
COL13: U1.21 (PD3); also elsewhere on the board
COL14: U1.19 (PD1); also elsewhere on the board
GND: C3.2, C4.1, CB1.2, CB2.2, CB3.2, CB4.2, CRGB1.2, CRGB2.2, CRGB3.2, CRGB4.2, CSH1.1, CSH2.1, CX1.2, CX2.2, DF1.2 (A), J1.A1 (GND), J1.A12 (GND), J1.B1 (GND), J1.B12 (GND), Q1.2 (S), RCC1.1, RCC2.2, RGB1.3 (VSS), RGB2.3 (VSS), RGB3.3 (VSS), RGB4.3 (VSS), RHWB1.2, RSH1.2, RSH2.2, RST1.1 (A), U1.5 (UGND), U1.15 (GND), U1.23 (GND), U1.35 (GND), U1.43 (GND), U1.45 (GND), U2.2 (GND), Y1.2, Y1.4
LED_GND: Q1.3 (D); also elsewhere on the board
unnamed: CSH2.2, DSH1.1 (K), RSH2.1
unnamed: J1.A5 (CC1), RCC1.2
unnamed: J1.B5 (CC2), RCC2.1
unnamed: Q1.1 (G), RPB1.2
unnamed: RGB1.2 (DOUT), RGB2.4 (DIN)
unnamed: RGB2.2 (DOUT), RGB3.4 (DIN)
unnamed: RGB3.2 (DOUT), RGB4.4 (DIN)
unnamed: RPB1.1, U1.12 (PB7)
unnamed: C3.1, U1.6 (UCAP)
unnamed: RHWB1.1, U1.33 (~HWB/PE2)
ROW0: U1.9 (PB1); also elsewhere on the board
ROW1: U1.10 (PB2); also elsewhere on the board
ROW2: U1.11 (PB3); also elsewhere on the board
ROW3: U1.41 (PF0); also elsewhere on the board
ROW4: U1.40 (PF1); also elsewhere on the board
VBUS: C4.2, F1.1, J1.A4 (VBUS), J1.A9 (VBUS), J1.B4 (VBUS), J1.B9 (VBUS), U2.5 (VBUS)
VCC: CB1.1, CB2.1, CB3.1, CB4.1, CRGB1.1, CRGB2.1, CRGB3.1, CRGB4.1, DF1.1 (K), F1.2, RGB1.1 (VDD), RGB2.1 (VDD), RGB3.1 (VDD), RGB4.1 (VDD), RRST1.2, U1.2 (UVCC), U1.7 (VBUS), U1.14 (VCC), U1.24 (AVCC), U1.34 (VCC), U1.44 (AVCC); also elsewhere on the board

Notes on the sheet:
Power Supply & Protection
Shield
Clock circuit
RGB Underglow Circuit
USB ESD
Hard reset circuit
USB Connector
Logos and flags
Microcontroller
Mounting holes
Case ESD
Stabilizers

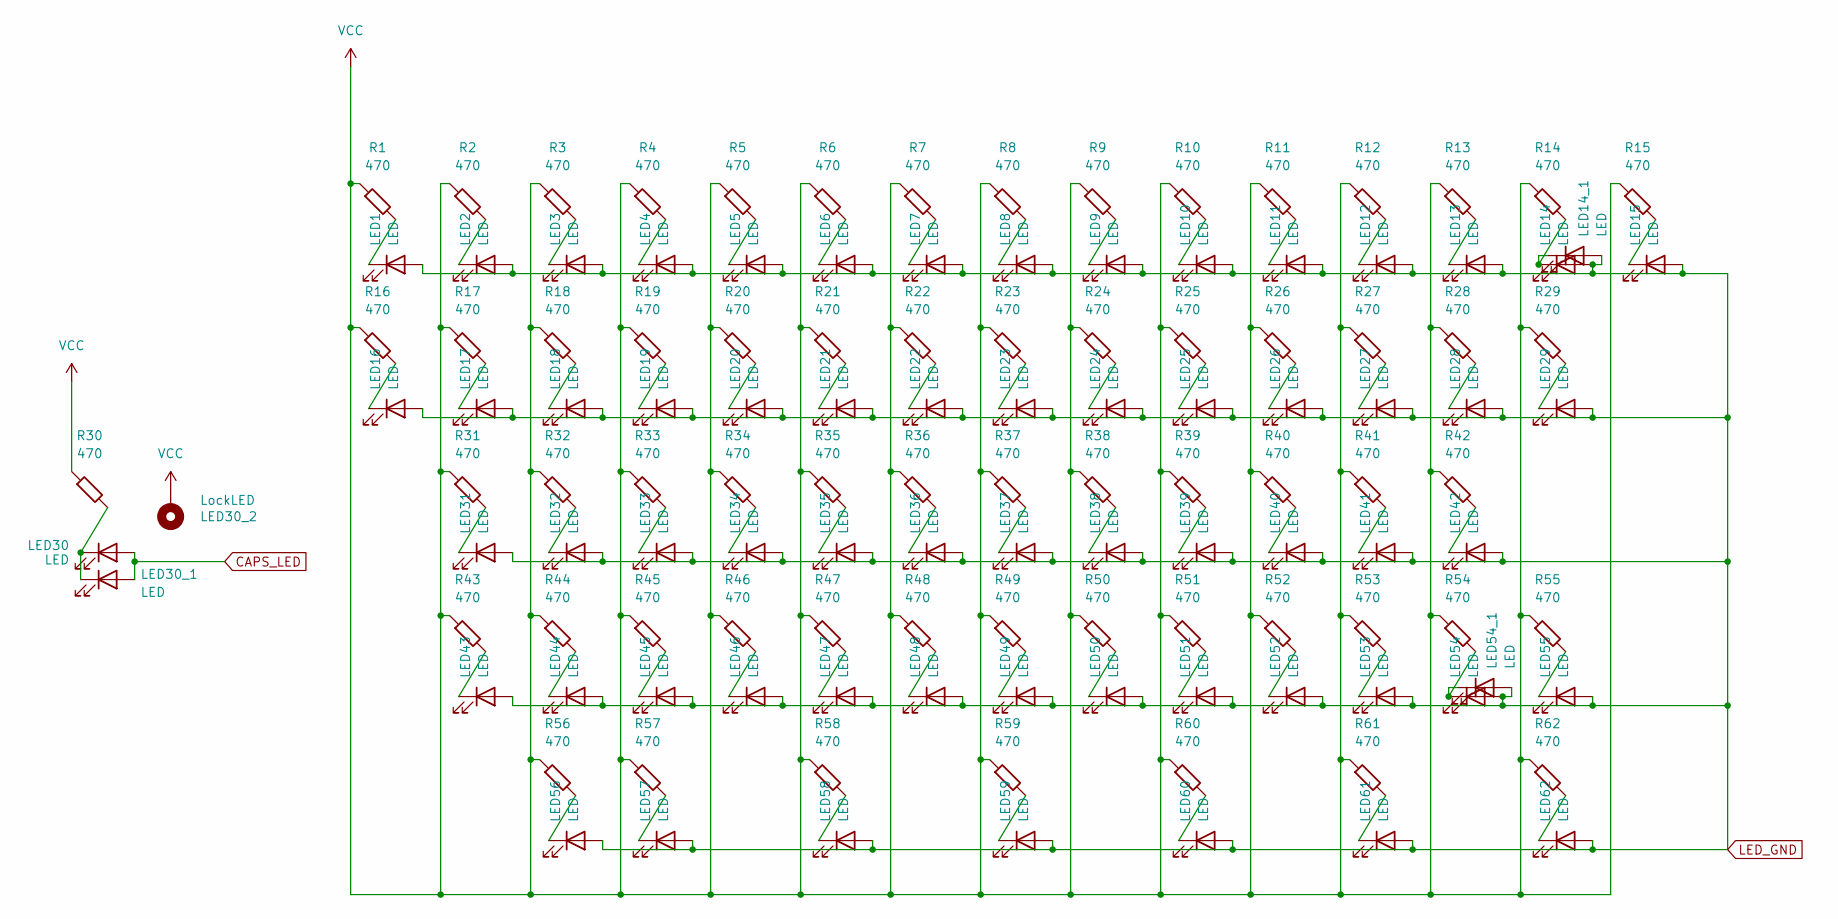
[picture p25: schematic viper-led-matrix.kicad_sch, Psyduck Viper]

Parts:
LED1, LED2, LED3, LED4, LED5, LED6, LED7, LED8, LED9, LED10, LED11, LED12, LED13, LED14, LED14_1, LED15, LED16, LED17, LED18, LED19, LED20, LED21, LED22, LED23, LED24, LED25, LED26, LED27, LED28, LED29, LED30, LED30_1, LED31, LED32, LED33, LED34, LED35, LED36, LED37, LED38, LED39, LED40, LED41, LED42, LED43, LED44, LED45, LED46, LED47, LED48, LED49, LED50, LED51, LED52, LED53, LED54, LED54_1, LED55, LED56, LED57, LED58, LED59, LED60, LED61, LED62: LED; MX-LED; LCSC C5440555
LED30_2: LockLED; MX-Lock-LED; LCSC C5440555
R1, R2, R3, R4, R5, R6, R7, R8, R9, R10, R11, R12, R13, R14, R15, R16, R17, R18, R19, R20, R21, R22, R23, R24, R25, R26, R27, R28, R29, R30, R31, R32, R33, R34, R35, R36, R37, R38, R39, R40, R41, R42, R43, R44, R45, R46, R47, R48, R49, R50, R51, R52, R53, R54, R55, R56, R57, R58, R59, R60, R61, R62: 470; R_0805_2012Metric; LCSC C17710

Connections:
CAPS_LED: LED30.2 (A), LED30_1.2 (A); also elsewhere on the board
LED_GND: LED1.2 (A), LED2.2 (A), LED3.2 (A), LED4.2 (A), LED5.2 (A), LED6.2 (A), LED7.2 (A), LED8.2 (A), LED9.2 (A), LED10.2 (A), LED11.2 (A), LED12.2 (A), LED13.2 (A), LED14.2 (A), LED14_1.2 (A), LED15.2 (A), LED16.2 (A), LED17.2 (A), LED18.2 (A), LED19.2 (A), LED20.2 (A), LED21.2 (A), LED22.2 (A), LED23.2 (A), LED24.2 (A), LED25.2 (A), LED26.2 (A), LED27.2 (A), LED28.2 (A), LED29.2 (A), LED31.2 (A), LED32.2 (A), LED33.2 (A), LED34.2 (A), LED35.2 (A), LED36.2 (A), LED37.2 (A), LED38.2 (A), LED39.2 (A), LED40.2 (A), LED41.2 (A), LED42.2 (A), LED43.2 (A), LED44.2 (A), LED45.2 (A), LED46.2 (A), LED47.2 (A), LED48.2 (A), LED49.2 (A), LED50.2 (A), LED51.2 (A), LED52.2 (A), LED53.2 (A), LED54.2 (A), LED54_1.2 (A), LED55.2 (A), LED56.2 (A), LED57.2 (A), LED58.2 (A), LED59.2 (A), LED60.2 (A), LED61.2 (A), LED62.2 (A); also elsewhere on the board
unnamed: LED1.1 (K), R1.2
unnamed: LED2.1 (K), R2.2
unnamed: LED3.1 (K), R3.2
unnamed: LED4.1 (K), R4.2
unnamed: LED5.1 (K), R5.2
unnamed: LED6.1 (K), R6.2
unnamed: LED7.1 (K), R7.2
unnamed: LED8.1 (K), R8.2
unnamed: LED9.1 (K), R9.2
unnamed: LED10.1 (K), R10.2
unnamed: LED11.1 (K), R11.2
unnamed: LED12.1 (K), R12.2
unnamed: LED13.1 (K), R13.2
unnamed: LED14.1 (K), LED14_1.1 (K), R14.2
unnamed: LED15.1 (K), R15.2
unnamed: LED16.1 (K), R16.2
unnamed: LED17.1 (K), R17.2
unnamed: LED18.1 (K), R18.2
unnamed: LED19.1 (K), R19.2
unnamed: LED20.1 (K), R20.2
unnamed: LED21.1 (K), R21.2
unnamed: LED22.1 (K), R22.2
unnamed: LED23.1 (K), R23.2
unnamed: LED24.1 (K), R24.2
unnamed: LED25.1 (K), R25.2
unnamed: LED26.1 (K), R26.2
unnamed: LED27.1 (K), R27.2
unnamed: LED28.1 (K), R28.2
unnamed: LED29.1 (K), R29.2
unnamed: LED30.1 (K), LED30_1.1 (K), R30.2
unnamed: LED31.1 (K), R31.2
unnamed: LED32.1 (K), R32.2
unnamed: LED33.1 (K), R33.2
unnamed: LED34.1 (K), R34.2
unnamed: LED35.1 (K), R35.2
unnamed: LED36.1 (K), R36.2
unnamed: LED37.1 (K), R37.2
unnamed: LED38.1 (K), R38.2
unnamed: LED39.1 (K), R39.2
unnamed: LED40.1 (K), R40.2
unnamed: LED41.1 (K), R41.2
unnamed: LED42.1 (K), R42.2
unnamed: LED43.1 (K), R43.2
unnamed: LED44.1 (K), R44.2
unnamed: LED45.1 (K), R45.2
unnamed: LED46.1 (K), R46.2
unnamed: LED47.1 (K), R47.2
unnamed: LED48.1 (K), R48.2
unnamed: LED49.1 (K), R49.2
unnamed: LED50.1 (K), R50.2
unnamed: LED51.1 (K), R51.2
unnamed: LED52.1 (K), R52.2
unnamed: LED53.1 (K), R53.2
unnamed: LED54.1 (K), LED54_1.1 (K), R54.2
unnamed: LED55.1 (K), R55.2
unnamed: LED56.1 (K), R56.2
unnamed: LED57.1 (K), R57.2
unnamed: LED58.1 (K), R58.2
unnamed: LED59.1 (K), R59.2
unnamed: LED60.1 (K), R60.2
unnamed: LED61.1 (K), R61.2
unnamed: LED62.1 (K), R62.2
VCC: LED30_2.1, R1.1, R2.1, R3.1, R4.1, R5.1, R6.1, R7.1, R8.1, R9.1, R10.1, R11.1, R12.1, R13.1, R14.1, R15.1, R16.1, R17.1, R18.1, R19.1, R20.1, R21.1, R22.1, R23.1, R24.1, R25.1, R26.1, R27.1, R28.1, R29.1, R30.1, R31.1, R32.1, R33.1, R34.1, R35.1, R36.1, R37.1, R38.1, R39.1, R40.1, R41.1, R42.1, R43.1, R44.1, R45.1, R46.1, R47.1, R48.1, R49.1, R50.1, R51.1, R52.1, R53.1, R54.1, R55.1, R56.1, R57.1, R58.1, R59.1, R60.1, R61.1, R62.1; also elsewhere on the board

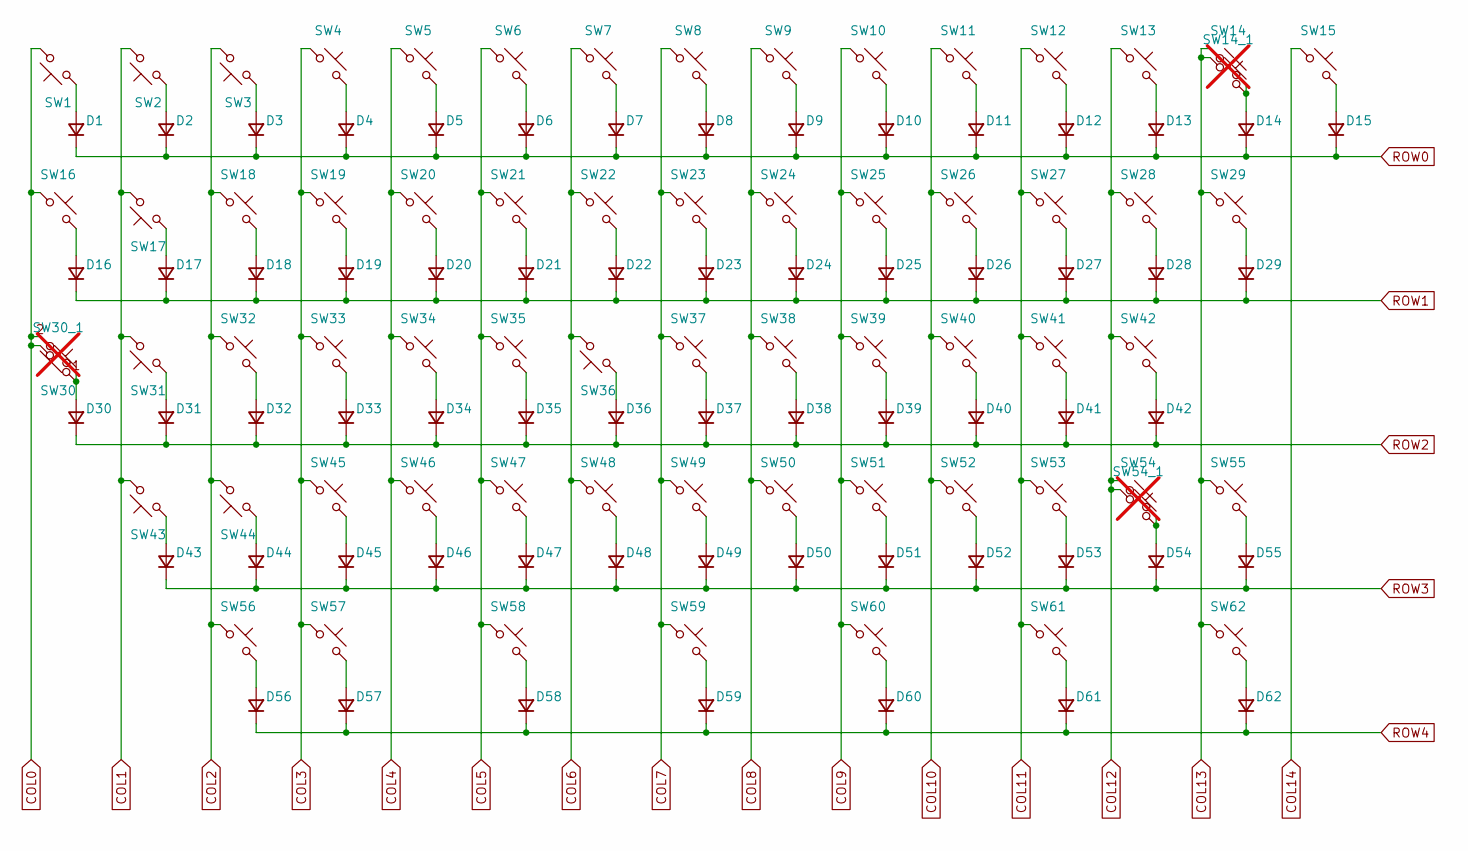
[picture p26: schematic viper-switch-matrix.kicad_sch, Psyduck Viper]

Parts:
D1, D2, D3, D4, D5, D6, D7, D8, D9, D10, D11, D12, D13, D14, D15, D16, D17, D18, D19, D20, D21, D22, D23, D24, D25, D26, D27, D28, D29, D30, D31, D32, D33, D34, D35, D36, D37, D38, D39, D40, D41, D42, D43, D44, D45, D46, D47, D48, D49, D50, D51, D52, D53, D54, D55, D56, D57, D58, D59, D60, D61, D62: 1N4148; D_0805_2012Metric; LCSC C109001
SW1, SW2, SW3, SW4, SW5, SW6, SW7, SW8, SW9, SW10, SW11, SW12, SW13, SW14_1, SW15, SW16, SW17, SW18, SW19, SW20, SW21, SW22, SW23, SW24, SW25, SW26, SW27, SW28, SW29, SW30_1, SW31, SW32, SW33, SW34, SW35, SW36, SW37, SW38, SW39, SW40, SW41, SW42, SW43, SW44, SW45, SW46, SW47, SW48, SW49, SW50, SW51, SW52, SW53, SW54_1, SW55, SW56, SW57, SW58, SW59, SW60, SW61, SW62: SW_Push; SW_Hybrid_Cherry_MX_Alps_1.00u_1
SW14, SW30, SW54: SW_Push; SW_Hybrid_Cherry_MX_Alps_1.00u_1; not fitted

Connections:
COL0: SW1.2, SW16.1, SW30.2, SW30_1.1; also elsewhere on the board
COL1: SW2.2, SW17.2, SW31.2, SW43.2; also elsewhere on the board
COL2: SW3.2, SW18.1, SW32.1, SW44.2, SW56.1; also elsewhere on the board
COL3: SW4.1, SW19.1, SW33.1, SW45.1, SW57.1; also elsewhere on the board
COL4: SW5.1, SW20.1, SW34.1, SW46.1; also elsewhere on the board
COL5: SW6.1, SW21.1, SW35.1, SW47.1, SW58.1; also elsewhere on the board
COL6: SW7.1, SW22.1, SW36.2, SW48.1; also elsewhere on the board
COL7: SW8.1, SW23.1, SW37.1, SW49.1, SW59.1; also elsewhere on the board
COL8: SW9.1, SW24.1, SW38.1, SW50.1; also elsewhere on the board
COL9: SW10.1, SW25.1, SW39.1, SW51.1, SW60.1; also elsewhere on the board
COL10: SW11.1, SW26.1, SW40.1, SW52.1; also elsewhere on the board
COL11: SW12.1, SW27.1, SW41.1, SW53.1, SW61.1; also elsewhere on the board
COL12: SW13.1, SW28.1, SW42.1, SW54.1, SW54_1.1; also elsewhere on the board
COL13: SW14.1, SW14_1.1, SW29.1, SW55.1, SW62.1; also elsewhere on the board
COL14: SW15.1; also elsewhere on the board
unnamed: D1.2 (A), SW1.1
unnamed: D2.2 (A), SW2.1
unnamed: D3.2 (A), SW3.1
unnamed: D4.2 (A), SW4.2
unnamed: D5.2 (A), SW5.2
unnamed: D6.2 (A), SW6.2
unnamed: D7.2 (A), SW7.2
unnamed: D8.2 (A), SW8.2
unnamed: D9.2 (A), SW9.2
unnamed: D10.2 (A), SW10.2
unnamed: D11.2 (A), SW11.2
unnamed: D12.2 (A), SW12.2
unnamed: D13.2 (A), SW13.2
unnamed: D14.2 (A), SW14.2, SW14_1.2
unnamed: D15.2 (A), SW15.2
unnamed: D16.2 (A), SW16.2
unnamed: D17.2 (A), SW17.1
unnamed: D18.2 (A), SW18.2
unnamed: D19.2 (A), SW19.2
unnamed: D20.2 (A), SW20.2
unnamed: D21.2 (A), SW21.2
unnamed: D22.2 (A), SW22.2
unnamed: D23.2 (A), SW23.2
unnamed: D24.2 (A), SW24.2
unnamed: D25.2 (A), SW25.2
unnamed: D26.2 (A), SW26.2
unnamed: D27.2 (A), SW27.2
unnamed: D28.2 (A), SW28.2
unnamed: D29.2 (A), SW29.2
unnamed: D30.2 (A), SW30.1, SW30_1.2
unnamed: D31.2 (A), SW31.1
unnamed: D32.2 (A), SW32.2
unnamed: D33.2 (A), SW33.2
unnamed: D34.2 (A), SW34.2
unnamed: D35.2 (A), SW35.2
unnamed: D36.2 (A), SW36.1
unnamed: D37.2 (A), SW37.2
unnamed: D38.2 (A), SW38.2
unnamed: D39.2 (A), SW39.2
unnamed: D40.2 (A), SW40.2
unnamed: D41.2 (A), SW41.2
unnamed: D42.2 (A), SW42.2
unnamed: D43.2 (A), SW43.1
unnamed: D44.2 (A), SW44.1
unnamed: D45.2 (A), SW45.2
unnamed: D46.2 (A), SW46.2
unnamed: D47.2 (A), SW47.2
unnamed: D48.2 (A), SW48.2
unnamed: D49.2 (A), SW49.2
unnamed: D50.2 (A), SW50.2
unnamed: D51.2 (A), SW51.2
unnamed: D52.2 (A), SW52.2
unnamed: D53.2 (A), SW53.2
unnamed: D54.2 (A), SW54.2, SW54_1.2
unnamed: D55.2 (A), SW55.2
unnamed: D56.2 (A), SW56.2
unnamed: D57.2 (A), SW57.2
unnamed: D58.2 (A), SW58.2
unnamed: D59.2 (A), SW59.2
unnamed: D60.2 (A), SW60.2
unnamed: D61.2 (A), SW61.2
unnamed: D62.2 (A), SW62.2
ROW0: D1.1 (K), D2.1 (K), D3.1 (K), D4.1 (K), D5.1 (K), D6.1 (K), D7.1 (K), D8.1 (K), D9.1 (K), D10.1 (K), D11.1 (K), D12.1 (K), D13.1 (K), D14.1 (K), D15.1 (K); also elsewhere on the board
ROW1: D16.1 (K), D17.1 (K), D18.1 (K), D19.1 (K), D20.1 (K), D21.1 (K), D22.1 (K), D23.1 (K), D24.1 (K), D25.1 (K), D26.1 (K), D27.1 (K), D28.1 (K), D29.1 (K); also elsewhere on the board
ROW2: D30.1 (K), D31.1 (K), D32.1 (K), D33.1 (K), D34.1 (K), D35.1 (K), D36.1 (K), D37.1 (K), D38.1 (K), D39.1 (K), D40.1 (K), D41.1 (K), D42.1 (K); also elsewhere on the board
ROW3: D43.1 (K), D44.1 (K), D45.1 (K), D46.1 (K), D47.1 (K), D48.1 (K), D49.1 (K), D50.1 (K), D51.1 (K), D52.1 (K), D53.1 (K), D54.1 (K), D55.1 (K); also elsewhere on the board
ROW4: D56.1 (K), D57.1 (K), D58.1 (K), D59.1 (K), D60.1 (K), D61.1 (K), D62.1 (K); also elsewhere on the board

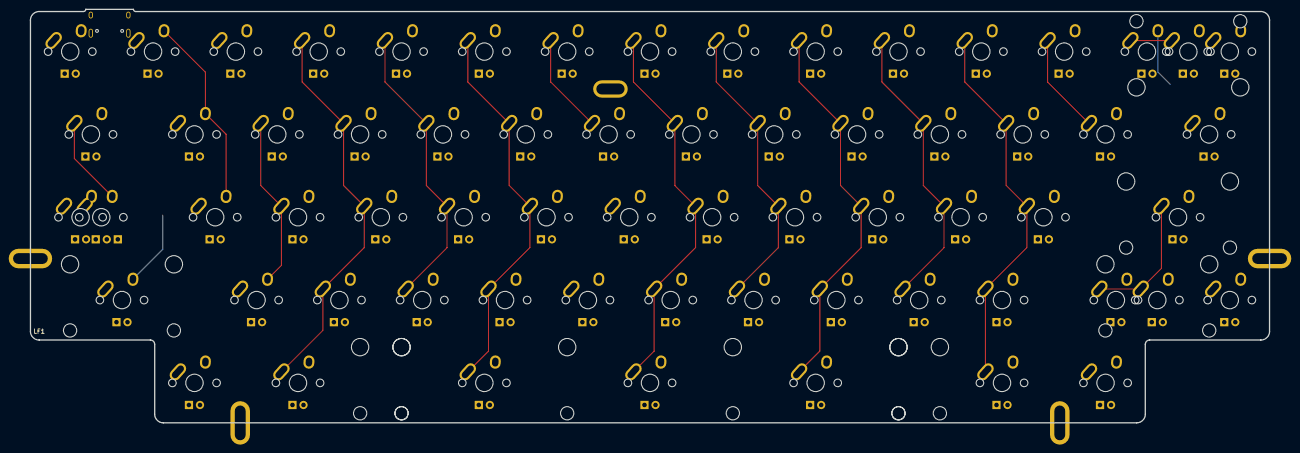
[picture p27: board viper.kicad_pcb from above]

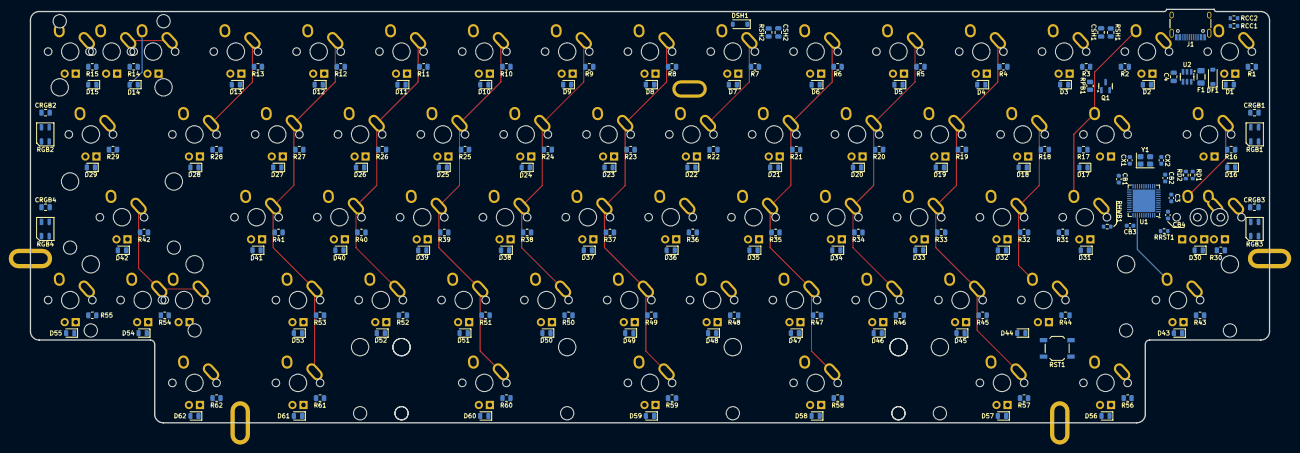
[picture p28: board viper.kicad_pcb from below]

Board: 2 copper layers, 285.0 x 95.1 mm, 309 parts (160 on the bottom side), 171 nets.

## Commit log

2025-05-17 Updated README & Dockerfile, included initial output
    [viper.kicad_pcb, viper.kicad_sch]
2025-05-17 Add updated export with stepped caps
    [viper.kicad_pcb, viper.kicad_sch]
2025-05-18 kle2netlist with layout & netlist xml
    [viper.kicad_pcb, viper.kicad_sch]
2025-05-26 Updated kle layout
    [viper.kicad_pcb, viper.kicad_sch]
2025-05-26 MX Hybrid PCB, diode alignment is strange
    [viper.kicad_pcb, viper.kicad_sch]
2025-05-28 converted switch/diode symbols to resistors/leds in generated schematic
    [viper_led_matrix.kicad_sch]
2025-05-28 use example diode placement
    [viper.kicad_pcb]
2025-06-04 hell yea
    [viper.kicad_pcb, viper.kicad_sch, viper_collapsed_led_matrix.kicad_sch]
2025-06-04 YAKE - YET ANOTHER KEYBOARD EXPORT
    [viper.kicad_pcb, viper.kicad_sch]
2025-06-05 Added LED matrix & RGB LEDs
    [viper.kicad_pcb, viper.kicad_sch]
2025-06-05 Placed parts with respect to SW1
    [viper.kicad_pcb, viper.kicad_sch]
2025-06-06 and the story continues
    [viper.kicad_pcb, viper.kicad_sch]
2025-06-06 Improved README, restructured repo
    Restructured repo
    [viper.kicad_pcb, viper.kicad_sch, viper_led_matrix.kicad_sch]
2025-06-06 kle2netlist docker output + atmega template & split-hhkb attempt
    [viper-split-hhkb.kicad_pcb, viper-split-hhkb.kicad_sch, viper.kicad_pcb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]
2025-06-06 Import KLE layout & added README notes
    Include via layout & generated collapsed kle layout based on viper_v1_via_url.txt
    Updated README & Dockerfile, included initial output
    format keyboard-layout-via.json
    KLE layout with stepped caps
    Add updated export with stepped caps
    Updated README with RAW data & screenshots
    converted collapsed layout to kle_internal format for kle2netlist
    fixed kle layout columns
    Updated kle layout
    MX Hybrid PCB, diode alignment is strange
    updated gitignore
    Removed ISO enter & Added Split HHKB bottom row
    Removed Split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
2025-06-06 Merg hardware/viper from dev to main
    [viper.kicad_pcb, viper.kicad_sch]
2025-06-06 Fix path in Dockerfile & remove SOD123 ref, will stick with 0805 for prototype
2025-06-06 Included schematic.svg in README
    Removed DNP flags
    [viper.kicad_sch]
2025-06-10 Updated docs
    Updated schematic & changed DSOD123F to 0805 footprints where needed
    [viper.kicad_sch]
2025-06-10 Set value for TVS diode + fuse, keep ERC warning just in case
    [viper.kicad_sch]
2025-06-10 Attach CAPS_LED
    [viper.kicad_sch]
2025-06-10 Manually corrected split-hhkb layout
    [viper-split-hhkb.kicad_pcb, viper-split-hhkb.kicad_sch, viper.kicad_sch]
2025-06-10 Add unrouted renders & updated schematic
2025-06-13 KLE layout for split hhkb + 10u
    Added layout2ledschematic patch with some notes
    Remove old KLE layouts
    [viper-split-hhkb.kicad_pcb, viper-split-hhkb.kicad_sch]
2025-06-15 Test with voyager60 pinout & kle2netlist
    Mock positions for rgb leds & ferrite bead
    Unrouted board with kle2netlist & pos2orient
    No per-switch leds yet
    Append docker build to existing schematic
    Update schematic from PCB
    Apply pos2orient file
    Add led matrix sheet, marked as DNP
    Use Switch_Misc/MX-LED-PolarityMarked in layout2ledschematic job
    Disable unneeded symbol/footprint libraries
    Added mock mxlockled symbol, dnp
    MX-Lock-LED based on MX-LED from ai03-2725/MX_V2
    Fixed courtyard of W_Hybrid_Cherry_MX_Alps_1.00u
    Started flipping switch symbols for better routing
    [viper-led-matrix.kicad_sch, viper-switch-matrix.kicad_sch, viper.kicad_pcb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]
2025-06-16 Reannotated IC/USB resistors
    [viper.kicad_pcb, viper.kicad_sch]
2025-06-16 Imported JP60 board rules & settings
    [viper.kicad_pcb]
2025-06-16 Included Cimos/KiCad-CustomDesignRules submodule with symlink to jlcpcb design rules
2025-06-16 Improved schematic
    [viper-switch-matrix.kicad_sch, viper.kicad_sch]
2025-06-17 Updated BOM
    Start with manufacturing files.
    [viper-led-matrix.kicad_sch, viper-switch-matrix.kicad_sch, viper.kicad_pcb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]
2025-06-17 Cleaned up WS2812B-Mini 3535 footprint
2025-06-17 Updated README with schematic exports
    [viper.kicad_sch]
2025-06-22 Debugging footprints for cleaner DRC
    Set soldermask properties & improved ref placement on back silkscreen
    Silkscreen ref placement & forked HRO type-c receptacle due to edge cut
    Flipping switches
    [viper-led-matrix.kicad_sch, viper-switch-matrix.kicad_sch, viper.kicad_pcb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]
